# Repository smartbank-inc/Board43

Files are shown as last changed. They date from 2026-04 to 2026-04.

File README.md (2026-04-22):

# Board43

Board43 is an RP2350A-based microcontroller development board. Flash PicoRuby or your favorite firmware and start hacking.

## Directory Structure

| Directory | Description | License |
| --- | --- | --- |
| [`docs/`](./docs) | Reference manual and its compiler | MIT (compiler) / CC BY-SA 4.0 (document content) |
| [`firmware/`](./firmware) | PicoRuby-based firmware | MIT |
| [`pcb/`](./pcb) | KiCad PCB design data | CERN-OHL-W-2.0 (some files under CC BY-SA 4.0) |
| [`playground/`](./playground) | Browser-based PicoRuby IDE | MIT |
| [`workshop/`](./workshop) | Workshop materials ([Japanese](https://github.com/smartbank-inc/Board43/blob/main/workshop/README.md) / [English](https://github.com/smartbank-inc/Board43/blob/main/workshop/README_en.md)) | CC BY-SA 4.0 |

## License

Each directory in this repository is licensed independently. See the `LICENSE` file or `README` in each directory for details.

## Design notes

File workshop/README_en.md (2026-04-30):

[日本語](README.md)

# Board43 Workshop: Display Your Icon on the LED Matrix

Use Board43 and PicoRuby to display pixel art on a 16×16 LED matrix.

## What You Need

- **Board43** — Yours to keep after the workshop
- **USB Cable Type-C** — Please return after the workshop
- **Your PC** — Use Chrome or Edge

---

## 1. Set Up the Tool

### 1-1. Connect Board43 to Your PC

Connect Board43 to your PC with the USB cable.

### 1-2. Open Board43 Playground

Open the following URL in your browser.

```
https://board43-playground.smartbank.workers.dev/
```

### 1-3. Connect via Serial

The setup screen will appear.

1. Leave the Baud Rate at **115200** and press the **Connect** button

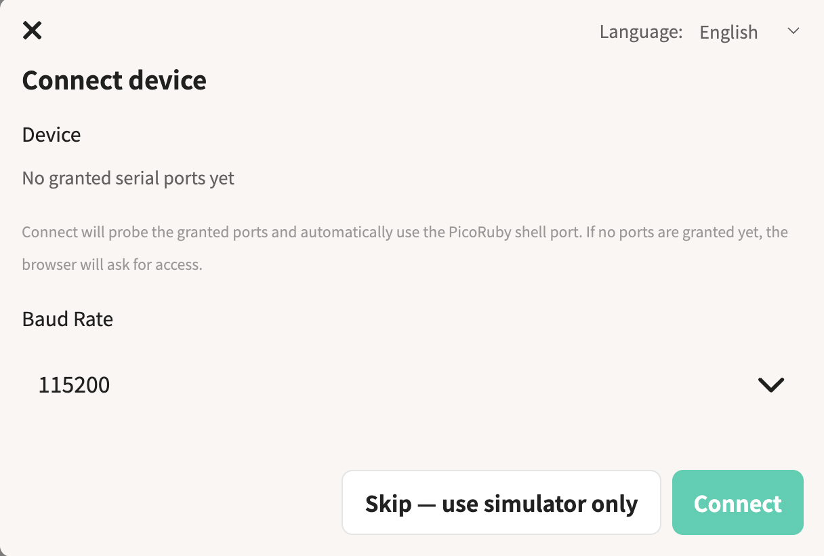
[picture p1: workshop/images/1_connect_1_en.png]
   

2. Select the serial port in the browser dialog (choose the one labeled "PicoRuby R2P2")

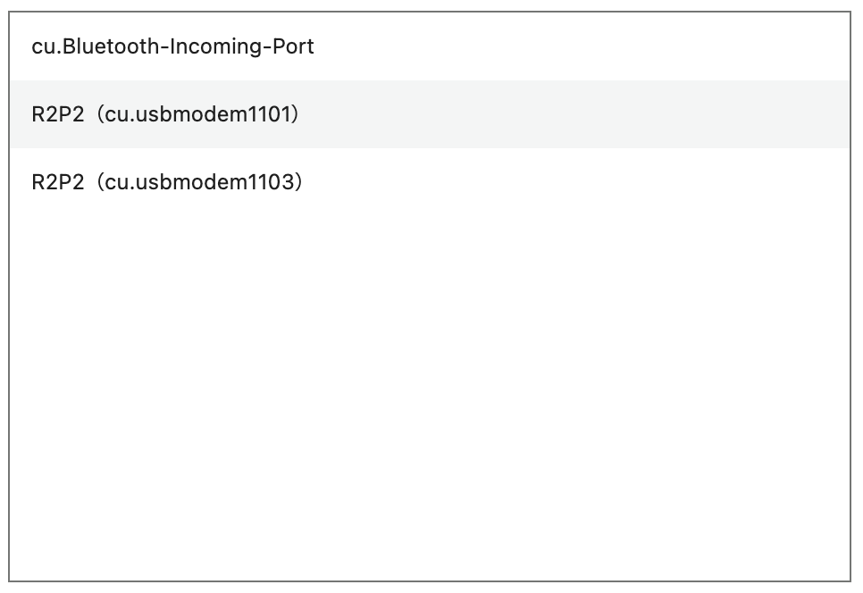
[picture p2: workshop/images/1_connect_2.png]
   

The screen will switch to show a code editor on the left, an LED simulator on the upper right, and a console at the bottom.

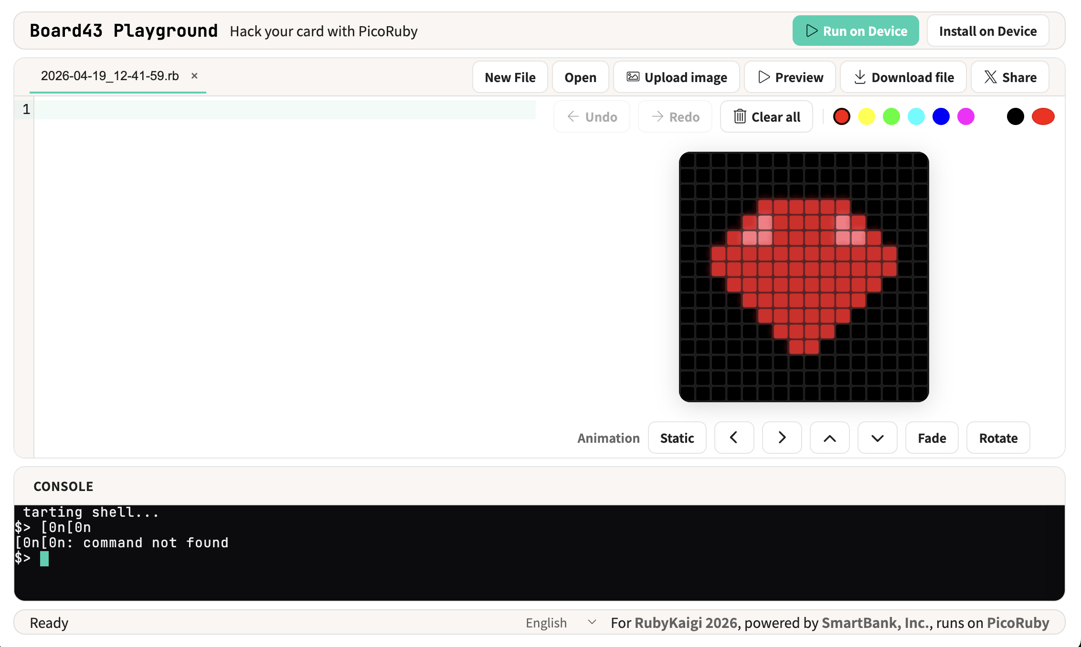
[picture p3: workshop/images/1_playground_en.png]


---

## 2. Light Up the LEDs

### 2-1. Light All LEDs in Red

Enter the following code in the editor.

```ruby
require 'ws2812-plus'

led = WS2812.new(pin: Board43::GPIO_LEDOUT, num: 256)  # GPIO 24, 256 LEDs (16×16)
led.fill(255, 0, 0)   # Set all LEDs to red (R=255, G=0, B=0)
led.show              # Send the buffer to the LEDs
```

Press the **Run on Device** button at the top of the screen.



If the entire LED matrix lights up red, it's working.

Press **Stop on Device** before running the next code.



### 2-2. Change the Color of Specific LEDs

Use `set_rgb(index, r, g, b)` to control individual LEDs.

```ruby
require 'ws2812-plus'

led = WS2812.new(pin: Board43::GPIO_LEDOUT, num: 256)

led.set_rgb(0, 0, 255, 0)      # Top-left to green
led.set_rgb(15, 0, 0, 255)     # Top-right to blue
led.set_rgb(100, 255, 255, 0)  # Index 100 to yellow

led.show
```

LED indices start at `0` in the top-left corner, going left to right, top to bottom.

```
  0   1   2   3  ...  15
 16  17  18  19  ...  31
 32  33  34  35  ...  47
  :                    :
240 241 242 243  ... 255
```

---

## 3. Animate the LEDs

Use `clear` to turn off all LEDs, and `sleep_ms` to wait in milliseconds. Repeating "off → on → wait" in a `loop` creates animation.

```ruby
require 'ws2812-plus'

led = WS2812.new(pin: Board43::GPIO_LEDOUT, num: 256)

loop do
  256.times do |i|
    led.clear                   # Turn off all LEDs
    led.set_rgb(i, 255, 0, 0)   # Light up LED i in red
    led.show
    sleep_ms 30                 # Wait 30 milliseconds
  end
end
```

Press **Run on Device** to see a red light flowing from the top-left to the bottom-right.

The `sleep_ms` value sets the frame interval — smaller values make it faster, larger values make it slower.

Press **Stop on Device** at the top of the screen to stop the program.

---

## 4. Display Your Icon

This is the main part. Use the **LED Simulator** in the upper right to create pixel art and display it on Board43.

### 4-1. Upload an Image

1. Press the **Upload image** button in the editor toolbar

   

2. Select an image file
3. It will be automatically converted to 16×16 and displayed in the simulator

### 4-2. Add Animation

Choose a display mode from the simulator toolbar.



| Option | Motion |
| --- | --- |
| Static | Static display  |
| ← | Scroll left |
| → | Scroll right |
| ↑ | Scroll up |
| ↓ | Scroll down |
| Fade | Fade in and out |
| Rotate | Rotate |

### 4-3. Preview in the Simulator

Press the **Preview** button in the editor to auto-generate code and preview the animation in the simulator.



### 4-4. Transfer to Board43

Press the **Run on Device** button at the top of the screen to display it on the Board43 LED matrix.

### 4-5. Tilt the Board

Try flipping Board43 upside down. The icon orientation changes automatically. The code generated from the uploaded image includes accelerometer-based orientation detection.

### 4-6. Experiment Freely

Change the pixel art or animation and try as many times as you like. Keep experimenting until you're satisfied.

### 4-7. Auto-Run on Power Up

Press the **Install on Device** button at the top of the screen to save the current code as `/home/app.rb`. From next time, the LEDs will light up just by powering on. It works with a mobile battery without a PC connection. On boot, the status LED blinks 10 times before app.rb starts.

To disable auto-run, skip the auto-run first, then delete or rename app.rb.

1. Hold the **SW3** button on the board and press the **RUN** button to reboot
2. Keep holding **SW3** until the status LED flashes 3 times
3. Press **Connect** again in the Playground screen, then delete or rename app.rb from the console

```
mv /home/app.rb /home/old.rb
```

### 4-8. Share Your Code

Press the **Share** button in the editor toolbar to generate a shareable URL. You can copy the link or post it to X (Twitter). Opening the shared link will load the code in Board43 Playground.

---

## 5. What Board43 Can Do

Board43 has a 6-axis IMU (accelerometer + gyroscope), buzzer, and switches in addition to the LED matrix.

**Demo: Theremin (theremin.rb)**
Tilt the board to play a musical scale. The LED shows the current note position. Uses the IMU, buzzer, LED, and switches.

The sample code is available on GitHub. Try it on your own Board43.

https://github.com/smartbank-inc/Board43/tree/main/workshop/examples

### Other Features

**Editor Toolbar**

| Button | Description |
| --- | --- |
| New File | Create a new file |
| Open | Open a file saved on Board43 |
| Download | Save the current file to your PC |

**Console**

The console is a PicoRuby shell. You can run commands directly from the terminal.

```
/home/my_program.rb   # Run a file
```

Press **Ctrl + C** to stop a running program.

```
ls /home          # List files
cat /home/app.rb  # Display file contents
mv /home/app.rb /home/old.rb  # Rename a file
```

---

## 6. Cleanup

Disconnect the USB cable and leave it on the desk. Please take Board43 home with you.

Please fill out the [survey](https://docs.google.com/forms/d/e/1FAIpQLSeV5AyQW6vzZo-vfc9GZmv4xTpa_p-nzMFEPl0KW-F13QeOgA/viewform). Your feedback will help us improve future workshops.

We'll be at this hack space after the workshop. We'd love to see what you've made. Feel free to ask questions too.

Sharing on social media is very welcome. We'd love it if you use the hashtag **#board43**.

---

## Troubleshooting

**LEDs don't light up**
→ Check that the USB cable is securely connected. If `>` appears in the console, the connection is working.

**The program won't stop**
→ Press the **Stop on Device** button at the top of the screen.

**Serial port not found**
→ Make sure you're using Chrome or Edge. Firefox and Safari don't support the Web Serial API.

**The screen is frozen**
→ Reload the browser and Connect again.

---

## License

[CC BY-SA 4.0](https://creativecommons.org/licenses/by-sa/4.0/), Attribution-ShareAlike 4.0 International.

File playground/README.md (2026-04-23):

# Board43 Playground

A browser-based PicoRuby IDE for the Board43.

## Features

### Editor

- Multi-file tabs with CodeMirror 6 (Ruby syntax highlighting)
- Create, open from device, and download files
- Context menu (cut/copy/paste)
- Inline LED simulator panel
  - Run Ruby code in-browser via PicoRuby WASM
  - 16x16 LED matrix preview
  - Pixel paint editor with color picker, undo/redo
  - Image upload (converts to LED pixel data, via [board43-image-transformer](./lib/board43-image-transformer) WASM)
  - Animation modes: Static, Scroll (Left/Right/Up/Down), Fade, Rotate

### Device Connection

- Web Serial API for Board43 hardware
- Setup wizard with serial port selection and baud rate configuration
- Run code on device / stop (Ctrl-C)
- Install as startup program (`/home/app.rb`)

### Terminal

- Ghostty-based serial console

### General

- Language support: English / Japanese
- Simulator-only mode (no device required)

## Getting started

Requires Node.js and `pnpm`.

```bash
pnpm install
pnpm dev
```

Open the printed URL in Chrome or Edge. Web Serial API is required for the
device features; the simulator works in any modern browser.

### Build

```bash
pnpm build
```

Emits a static SPA to `dist/`. Serve it with any static host.

## License

MIT. See [LICENSE](./LICENSE) for detail.

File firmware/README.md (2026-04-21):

# Firmware

## Submodules

- [PicoRuby](https://github.com/picoruby/picoruby) [`3.4.2`](https://github.com/picoruby/picoruby/tree/9b94521d56e6082793db861801546fc5808b5211)

R2P2 lives inside PicoRuby as the `picoruby-r2p2` mrbgem, and Pico SDK / Pico Extras are pulled in under it as nested submodules.

## Setup, Build, and Flash

See [docs](../docs) for detail.

## Release (CI build)

Pushing a tag shaped `firmware-YYYY-MM-DD-NN` triggers [`build-firmware.yml`](../.github/workflows/build-firmware.yml), which builds the UF2, uploads it as a workflow artifact, and creates a GitHub Release for the tag with the UF2 attached.

```console
$ git tag firmware-2026-04-15-01
$ git push origin firmware-2026-04-15-01
```

`NN` is a two-digit sequence for multiple builds on the same day (`01`, `02`, ...). The workflow also accepts manual runs via `workflow_dispatch` in the GitHub Actions UI.

Download the built UF2 from the [Releases](https://github.com/smartbank-inc/Board43-draft/releases) page, or via CLI:

```console
$ gh release download firmware-2026-04-15-01 --pattern '*.uf2'
```

## License

MIT. See [LICENSE](./LICENSE) for detail.

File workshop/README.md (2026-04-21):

[English](README_en.md)

# Board43 ワークショップ: 自分のアイコンをLEDマトリクスに表示しよう

Board43とPicoRubyを使って、16×16のLEDマトリクスにドット絵で表示させます。

## 使うもの

- **Board43** — ワークショップ後はお持ち帰りいただけます
- **USBケーブル Type-C** — ワークショップ後にお戻しください
- **ご自身のPC** — Chrome または Edge を使います

---

## 1. ツールを立ち上げる

### 1-1. Board43をPCに接続する

USBケーブルでBoard43をPCにつなぎます。

### 1-2. Board43 Playgroundを開く

ブラウザで以下のURLにアクセスします。

```
https://board43-playground.smartbank.workers.dev/
```

### 1-3. シリアル接続する

セットアップ画面が表示されます。

1. Baud Rate は **115200** のまま、 **Connect** ボタンを押す

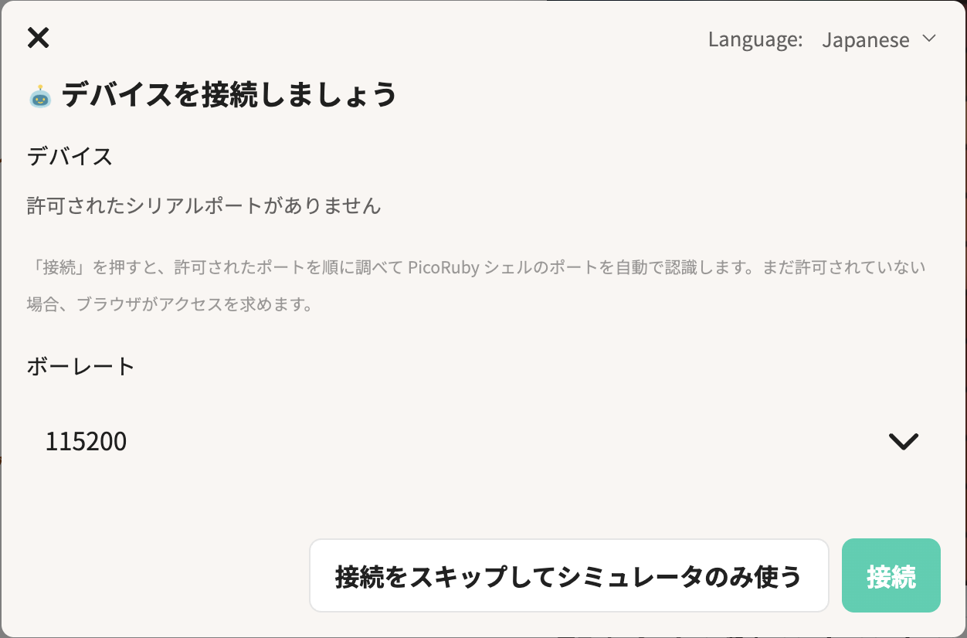
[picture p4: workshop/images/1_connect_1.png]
    

2. ブラウザのダイアログでシリアルポートを選ぶ（「PicoRuby R2P2」と表示されるものを選んでください）

    
    
画面が切り替わり、左にコードエディタ、右上にLEDシミュレータ、下にコンソールが表示されます。

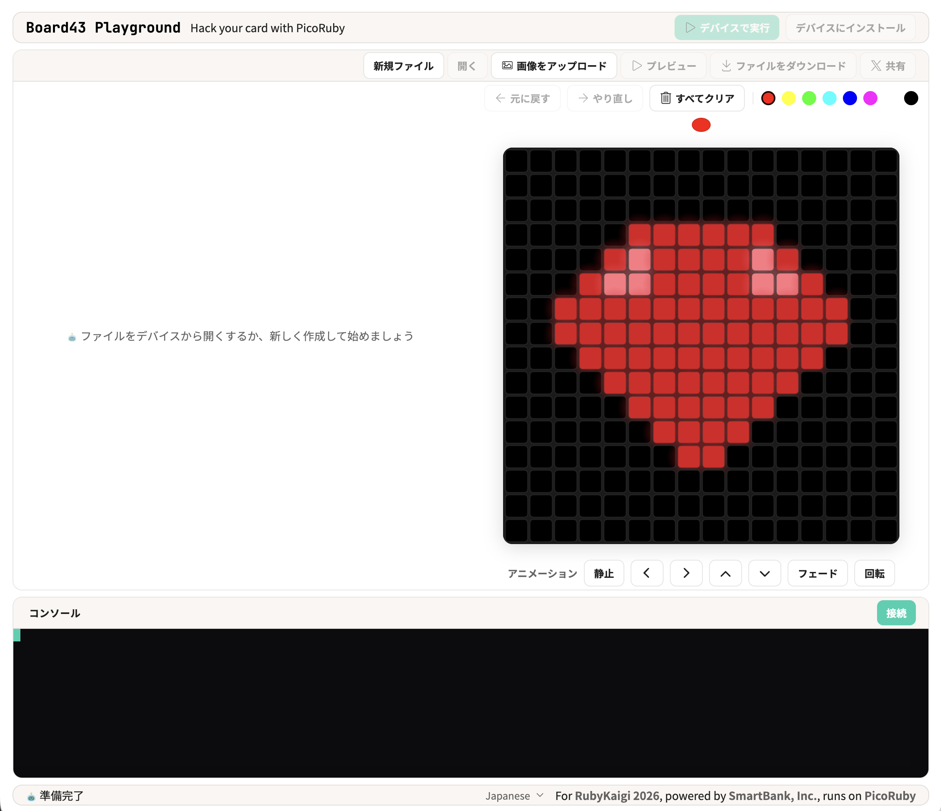
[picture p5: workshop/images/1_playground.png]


---

## 2. LEDを光らせてみよう

### 2-1. 全部赤く光らせる

エディタに以下のコードを入力します。

```ruby
require 'ws2812-plus'

led = WS2812.new(pin: Board43::GPIO_LEDOUT, num: 256)  # GPIO 24, LED 256個（16×16）
led.fill(255, 0, 0)   # 全LEDを赤（R=255, G=0, B=0）に
led.show              # バッファの内容をLEDに送信
```

画面上部の **Run on Device** ボタンを押してください。



LEDマトリクスが全面赤く光れば成功です。

次のコードを実行する前に **Stop on Device** を押してください。



### 2-2. 好きな場所の色を変える

`set_rgb(index, r, g, b)` で個別のLEDを指定できます。

```ruby
require 'ws2812-plus'

led = WS2812.new(pin: Board43::GPIO_LEDOUT, num: 256)

led.set_rgb(0, 0, 255, 0)      # 左上を緑に
led.set_rgb(15, 0, 0, 255)     # 右上を青に
led.set_rgb(100, 255, 255, 0)  # 100番目を黄色に

led.show
```

LEDのインデックスは左上が `0` で、左から右・上から下の順に並んでいます。

```
  0   1   2   3  ...  15
 16  17  18  19  ...  31
 32  33  34  35  ...  47
  :                    :
240 241 242 243  ... 255
```

---

## 3. アニメーションさせよう

`clear` で全消灯、`sleep_ms` でミリ秒単位の待機ができます。`loop` で「消灯→点灯→待機」を繰り返すことでアニメーションになります。

```ruby
require 'ws2812-plus'

led = WS2812.new(pin: Board43::GPIO_LEDOUT, num: 256)

loop do
  256.times do |i|
    led.clear                   # 全LED消灯
    led.set_rgb(i, 255, 0, 0)   # i番目を赤く光らせる
    led.show
    sleep_ms 30                 # 30ミリ秒待つ
  end
end
```

**Run on Device** で実行すると、赤い光が左上から右下へ流れていきます。

`sleep_ms` の値がフレーム間隔になるので、値を小さくすると速く、大きくするとゆっくり流れます。

プログラムを止めるときは画面上部の **Stop on Device** ボタンを押してください。

---

## 4. 自分のアイコンを光らせよう

ここからがメインです。画面右上の **LEDシミュレータ** を使ってドット絵を作り、Board43に表示させます。

### 4-1. 画像をアップロードする

1. エディタのツールバーにある **Upload image** ボタンを押す

    

2. 画像ファイルを選択する
3. 自動的に16×16に変換されてシミュレータに表示される

### 4-2. アニメーションをつける

シミュレータのツールバーで、表示方法を選べます。



| 選択肢 | 動き |
| --- | --- |
| Static | 静止表示 |
| ← | 左にスクロール |
| → | 右にスクロール |
| ↑ | 上にスクロール |
| ↓ | 下にスクロール |
| Fade | フェードイン・アウト |

### 4-3. シミュレータで確認する

エディタの **Preview** ボタンを押すと、コードが自動生成され、アニメーションがシミュレータ上でプレビューできます。



### 4-4. Board43に転送して光らせる

画面上部の **Run on Device** ボタンを押すと、Board43のLEDマトリクスに表示されます。

### 4-5. ボードを傾けてみよう

Board43を上下にひっくり返してみてください。アイコンの向きが自動的に変わります。アップロードした画像から生成されるコードには、加速度センサーで上下を検知する処理が含まれています。

### 4-6. 自由に試してみよう

ドット絵やアニメーションを変えて、何度でも試せます。納得いくまでいろいろ試してみてください。

### 4-7. 電源を入れただけでコードを実行する

画面上部の **Install on Device** ボタンを押すと、現在のコードが `/home/app.rb` として保存され、次回から電源を入れるだけでLEDが光ります。PCに接続しなくても、モバイルバッテリーで動きます。起動時にステータスLEDが10回点滅したあとに app.rb が実行されます。

自動起動を解除したい場合は、自動起動をスキップしてから app.rb を削除・変更します。

1. 基板の **SW3** ボタンを押したまま **RUN** ボタンを押して再起動する
2. ステータスLEDが3回フラッシュするまで **SW3** ボタンを押したままにする
3. Playground画面で **Connect** を押し直し、コンソールから app.rb を削除または別名に変更する

```
mv /home/app.rb /home/old.rb
```

### 4-8. コードをシェアしよう

エディタツールバーの **Share** ボタンを押すと、共有用のURLが生成されます。リンクをコピーしたり、X（Twitter）に投稿できます。共有リンクを開くと、Board43 Playgroundにコードが展開されます。

---

## 5. Board43でできること

Board43にはLEDマトリクス以外にも、6軸IMU（加速度・ジャイロセンサー）、ブザー、スイッチが搭載されています。

**デモ: テルミン（theremin.rb）**
ボードを傾けて音階を演奏できます。LEDが現在の音の位置を表示します。IMU、ブザー、LED、スイッチを使っています。

このサンプルコードはGitHubで公開しています。ご自身のBoard43でぜひ試してみてください。

https://github.com/smartbank-inc/Board43/workshop/examples

### その他の機能

**エディタのツールバー**

| ボタン | 説明 |
| --- | --- |
| New File | 新しいファイルを作成する |
| Open | Board43に保存されているファイルを開く |
| Download | 現在のファイルをPCに保存する |

**コンソール**

コンソールはPicoRubyのシェルです。ターミナルから直接コマンドを実行できます。

```
/home/my_program.rb   # ファイルを指定して実行
```

実行中のプログラムは **Ctrl + C** で停止できます。

```
ls /home          # ファイル一覧
cat /home/app.rb  # ファイルの中身を表示
mv /home/app.rb /home/old.rb  # ファイル名の変更
```

---

## 6. 片付け

USBケーブルを外して、机の上に置いてください。Board43はお持ち帰りください。

[アンケート](https://docs.google.com/forms/d/e/1FAIpQLSeV5AyQW6vzZo-vfc9GZmv4xTpa_p-nzMFEPl0KW-F13QeOgA/viewform)にご協力ください。今後のワークショップの参考にさせていただきます。

ワークショップ後もこのハックスペースにいます。できたものを見せに来てもらえるとうれしいです。質問もお気軽にどうぞ。

SNSでのシェアも大歓迎です。 **#board43** をつけてもらえると見に行けるのでうれしいです。

---

## トラブルシューティング

**LEDが光らない**
→ USBケーブルがしっかり接続されているか確認してください。コンソールに `>` が表示されていれば接続は正常です。

**プログラムが止まらない**
→ 画面上部の **Stop on Device** ボタンを押してください。

**シリアルポートが見つからない**
→ Chrome または Edge を使っているか確認してください。Firefox や Safari は Web Serial API に対応していません。

**画面が固まった**
→ ブラウザをリロードして、再度 Connect してください。

---

## License

[CC BY-SA 4.0](https://creativecommons.org/licenses/by-sa/4.0/), Attribution-ShareAlike 4.0 International.

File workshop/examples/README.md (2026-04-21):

[English](README_en.md)

# Board43 サンプルコード

## センサーごとのサンプル

| ファイル | 説明 | 使用機能 |
| --- | --- | --- |
| [status_led.rb](status_led.rb) | ステータスLEDのオン・オフ | GPIO |
| [button.rb](button.rb) | ボタンの押下状態を読み取る | スイッチ (GPIO) |
| [buzzer.rb](buzzer.rb) | ブザーを鳴らす・止める | ブザー (PWM) |
| [led_matrix.rb](led_matrix.rb) | LEDマトリクスに虹色グラデーションを表示する | LED (WS2812) |
| [imu.rb](imu.rb) | 加速度・ジャイロ・温度の値をコンソールに表示する | IMU (I2C) |

## 複合サンプル

| ファイル | 説明 | 使用機能 |
| --- | --- | --- |
| [water.rb](water.rb) | ボードを傾けると水が流れる流体シミュレーション | IMU + LED |
| [logo.rb](logo.rb) | RubyKaigi 2026ロゴ表示＋ボタンで背景エフェクト切り替え | スイッチ + LED + ブザー |
| [drum.rb](drum.rb) | 4つのボタンで叩くドラム | スイッチ (IRQ) + LED + ブザー |
| [snake_game.rb](snake_game.rb) | ボタンで操作するスネークゲーム | スイッチ + LED + ブザー |
| [theremin.rb](theremin.rb) | ボードを傾けて音階を演奏するテルミン | IMU + LED + ブザー + スイッチ |

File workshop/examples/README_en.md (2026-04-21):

[日本語](README.md)

# Board43 Sample Code

## Per-Sensor Samples

| File | Description | Features Used |
| --- | --- | --- |
| [status_led.rb](status_led.rb) | Toggle the status LED on/off | GPIO |
| [button.rb](button.rb) | Read button press state | Switches (GPIO) |
| [buzzer.rb](buzzer.rb) | Play and stop the buzzer | Buzzer (PWM) |
| [led_matrix.rb](led_matrix.rb) | Display a rainbow gradient on the LED matrix | LED (WS2812) |
| [imu.rb](imu.rb) | Print acceleration, gyroscope, and temperature to console | IMU (I2C) |

## Combined Samples

| File | Description | Features Used |
| --- | --- | --- |
| [water.rb](water.rb) | Tilt the board to make water flow — a fluid simulation | IMU + LED |
| [logo.rb](logo.rb) | RubyKaigi 2026 logo display with button-switchable background effects | Switches + LED + Buzzer |
| [drum.rb](drum.rb) | Play drums with 4 buttons | Switches (IRQ) + LED + Buzzer |
| [snake_game.rb](snake_game.rb) | Classic snake game controlled with buttons | Switches + LED + Buzzer |
| [theremin.rb](theremin.rb) | Tilt the board to play a musical scale | IMU + LED + Buzzer + Switches |

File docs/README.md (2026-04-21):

# docs

Reference manual and its compiler.

## Prerequisites

- [Rust](https://www.rust-lang.org/)

## Usage

```console
$ cargo run -- compile
```

## Release (CI build)

Pushing a tag shaped `document-MAJOR.MINOR.PATCH` triggers [`build-document.yml`](../.github/workflows/build-document.yml), which compiles the reference manual and creates a GitHub Release for the tag with the PDF attached.

```console
$ git tag document-1.0.0
$ git push origin document-1.0.0
```

The workflow also accepts manual runs via `workflow_dispatch` in the GitHub Actions UI (manual runs build the PDF but do not create a release).

If a document release is published after a firmware release, keep the firmware release marked as "Latest release" on GitHub (uncheck "Set as the latest release" when creating the document release). The reference manual directs readers to [`releases/latest`](https://github.com/smartbank-inc/Board43/releases/latest) for firmware downloads, so that tag must continue to resolve to the shippable firmware build.

Download the released PDF from the [Releases](https://github.com/smartbank-inc/Board43-draft/releases) page, or via CLI:

```console
$ gh release download document-1.0.0 --pattern '*.pdf'
```

## License

Source code (the document compiler) is licensed under the MIT. See [LICENSE](./LICENSE) for detail.

Document content (the reference manual text and assets) is licensed under [Creative Commons Attribution-ShareAlike 4.0 International (CC BY-SA 4.0)](https://creativecommons.org/licenses/by-sa/4.0/). Product names, trademarks, and registered trademarks referenced in this manual are the property of their respective owners. The license above does not grant any rights to use them.

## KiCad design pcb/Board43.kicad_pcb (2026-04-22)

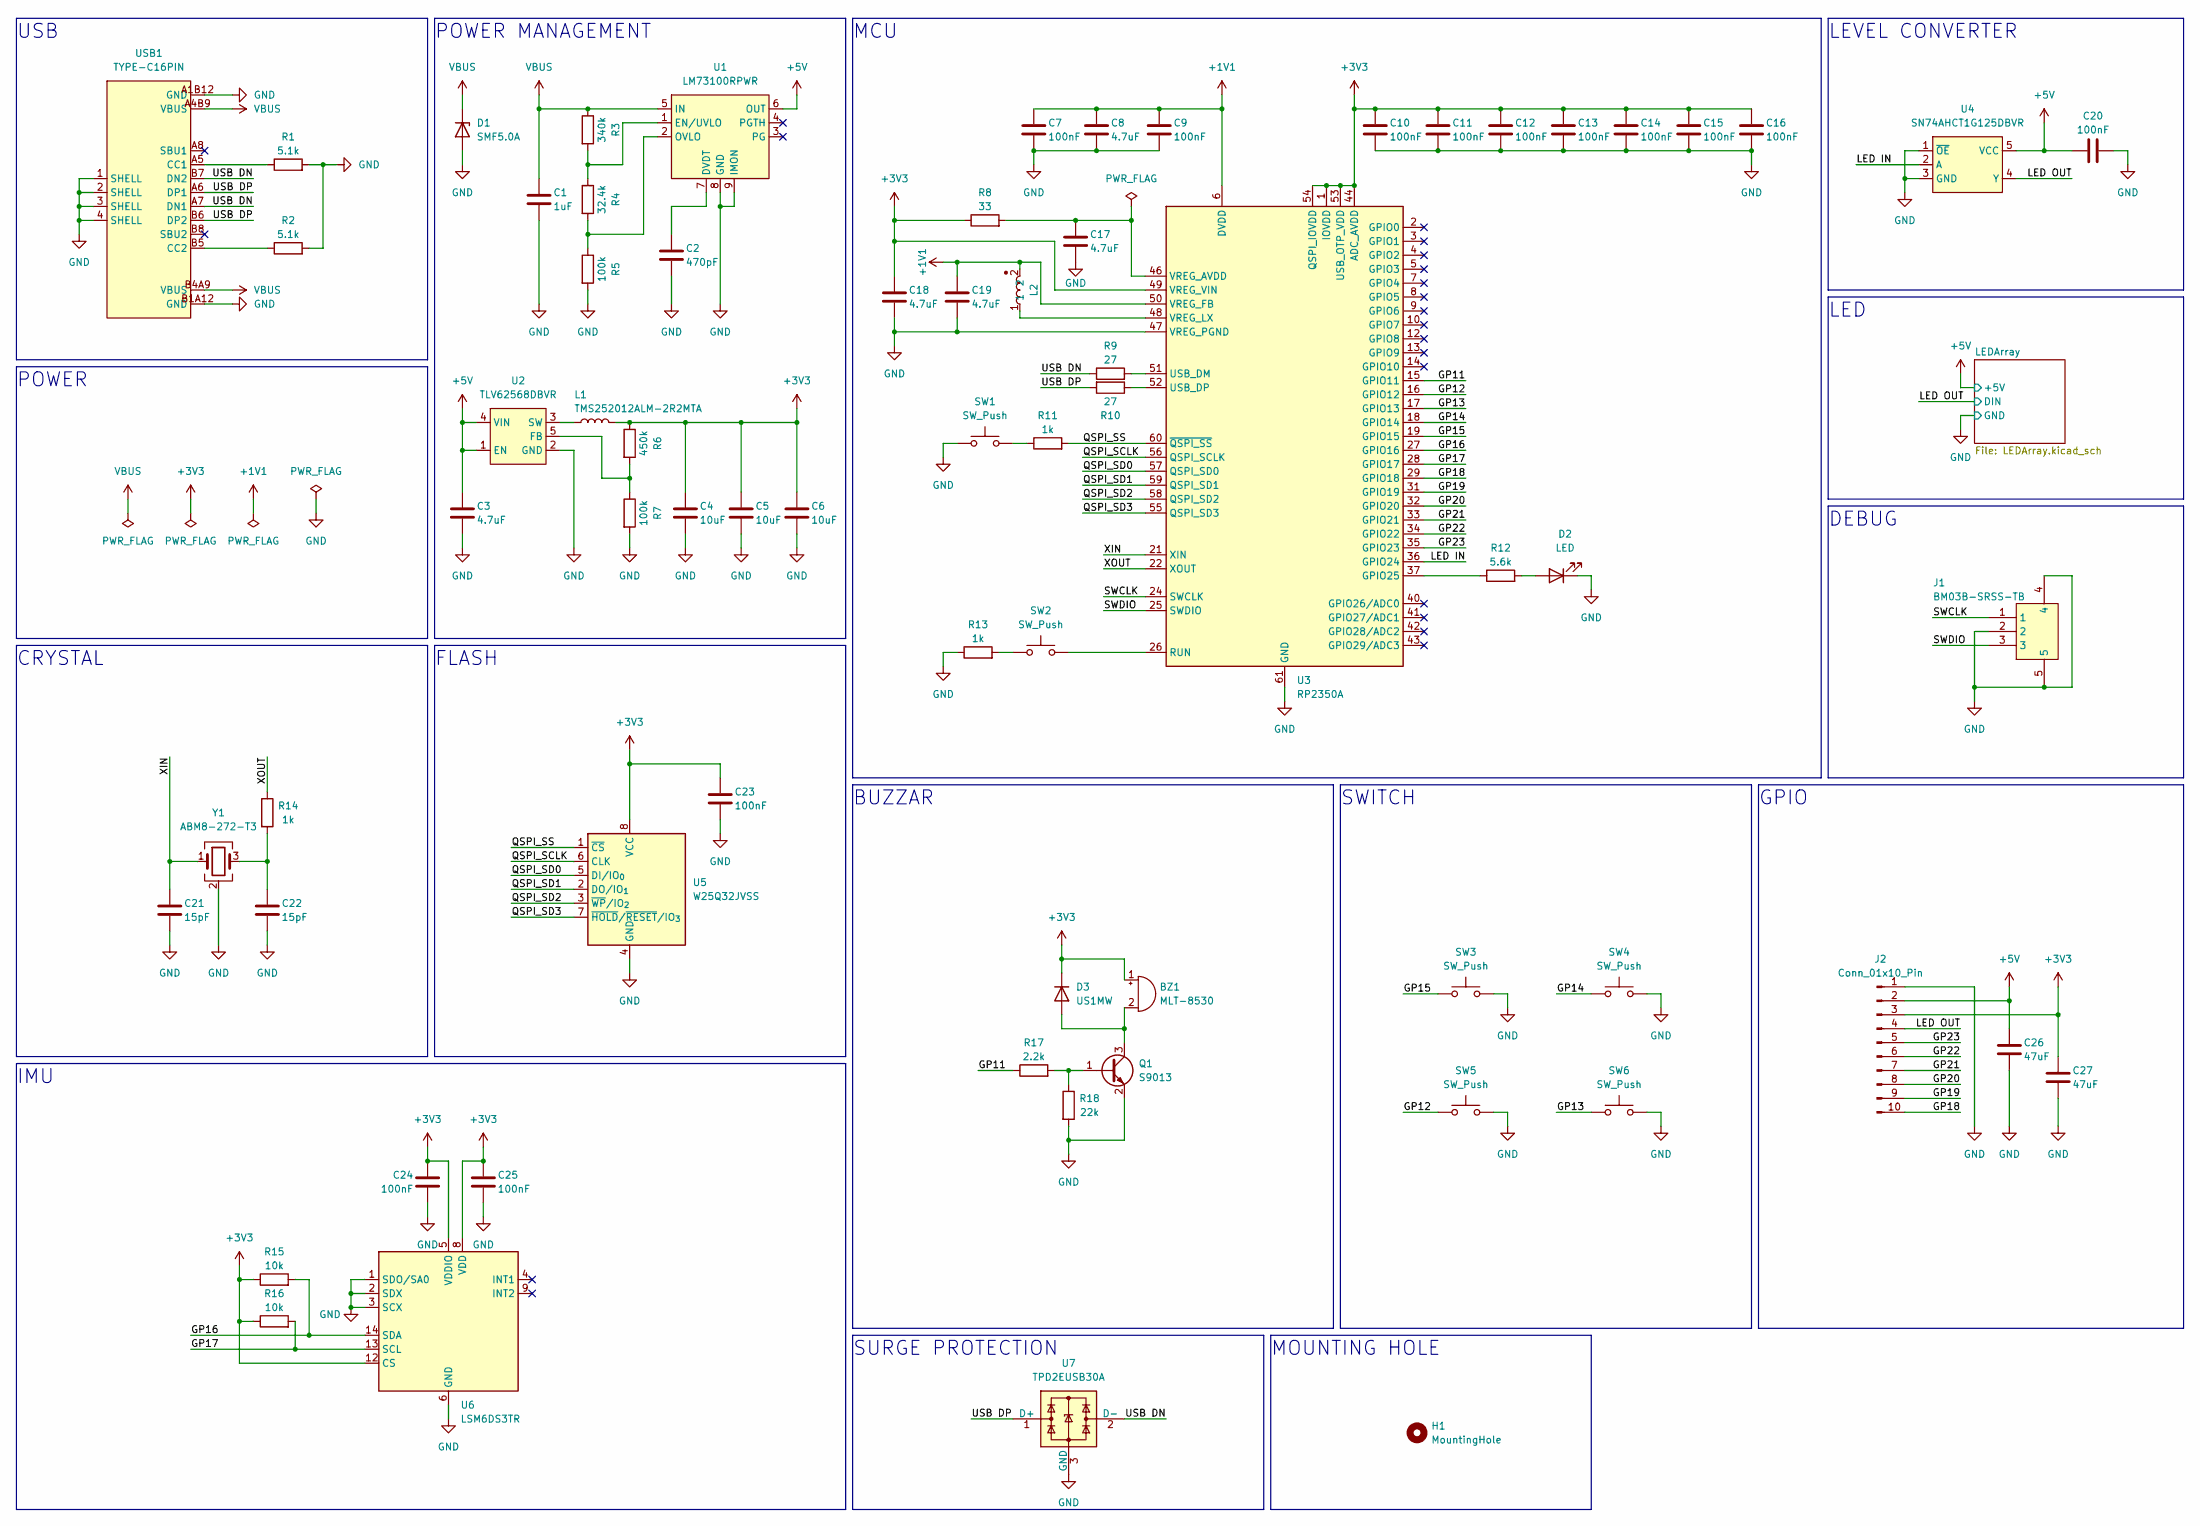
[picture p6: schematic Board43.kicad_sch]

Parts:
BZ1: MLT-8530; LCSC C94599
C1: 1uF; C_0402_1005Metric; LCSC C528974
C2: 470pF; C_0201_0603Metric; LCSC C384950
C3, C8, C17: 4.7uF; C_0402_1005Metric; LCSC C368809
C4, C5, C6: 10uF; C_0603_1608Metric; LCSC C2959727
C7, C9, C10, C11, C12, C13, C14, C15, C16: 100nF; C_0201_0603Metric; LCSC C668346
C18, C19: 4.7uF; C_0402_1005Metric_Narrow; LCSC C368809
C20, C23, C24, C25: 100nF; C_0402_1005Metric; LCSC C1525
C21, C22: 15pF; C_0402_1005Metric; LCSC C76950
C26, C27: 47uF; C_1206_3216Metric; LCSC C96123
D1: SMF5.0A; D_SOD-123F; LCSC C193402
D2: LED; KT-0603W; LCSC C2290
D3: US1MW; D_SOD-123F; LCSC C116132
H1: MountingHole; MountingHole_3.2mm_M3
J1: BM03B-SRSS-TB; LCSC C160389
J2: Conn_01x10_Pin; PinHeader_1x10_P2.54mm_Vertical
L1: TMS252012ALM-2R2MTA; L_1008_2520Metric; LCSC C1017131
L2: L; AOTA-B201610S3R3-101-T; LCSC C42411119
Q1: S9013; SOT-23; LCSC C727139
R1, R2: 5.1k; R_0201_0603Metric; LCSC C270344
R3: 340k; R_0402_1005Metric; LCSC C423187
R4: 32.4k; R_0402_1005Metric; LCSC C26974
R5, R7: 100k; R_0402_1005Metric; LCSC C25741
R6: 450k; R_0402_1005Metric; LCSC C5159688
R8: 33; R_0402_1005Metric; LCSC C25105
R9, R10: 27; R_0201_0603Metric; LCSC C473051
R11, R13, R14: 1k; R_0201_0603Metric; LCSC C270365
R12: 5.6k; R_0201_0603Metric; LCSC C423481
R15, R16: 10k; R_0201_0603Metric; LCSC C270334
R17: 2.2k; R_0402_1005Metric; LCSC C25879
R18: 22k; R_0402_1005Metric; LCSC C25768
SW1, SW2, SW3, SW4, SW5, SW6: SW_Push; SKRPACE010; LCSC C139797
U1: LM73100RPWR; LCSC C3210761
U2: TLV62568DBVR; SOT-23-5; LCSC C163219
U3: RP2350A; LCSC C42411118
U4: SN74AHCT1G125DBVR; SOT-23-5; LCSC C7484
U5: W25Q32JVSS; SOIC-8_5.3x5.3mm_P1.27mm; LCSC C82344
U6: LSM6DS3TR; LGA-14_3x2.5mm_P0.5mm_LayoutBorder3x4y; LCSC C95230
U7: TPD2EUSB30A; TPD2EUSB30ADRTR; LCSC C94934
USB1: TYPE-C16PIN; LCSC C393939
Y1: ABM8-272-T3; Crystal_SMD_3225-4Pin_3.2x2.5mm; LCSC C20625731

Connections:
+1V1: C7.1, C8.1, C9.1, C19.1, L2.2, U3.6 (DVDD), U3.23 (DVDD), U3.39 (DVDD), U3.50 (VREG_FB)
+3V3: BZ1.1 (+), C4.1, C5.1, C6.1, C10.1, C11.1, C12.1, C13.1, C14.1, C15.1, C16.1, C18.1, C23.1, C24.2, C25.1, C27.1, D3.1 (K), J2.3, L1.2, R6.1, R8.1, R15.1, R16.1, U3.1 (IOVDD), U3.11 (IOVDD), U3.20 (IOVDD), U3.30 (IOVDD), U3.38 (IOVDD), U3.44 (ADC_AVDD), U3.45 (IOVDD), U3.49 (VREG_VIN), U3.53 (USB_OTP_VDD), U3.54 (QSPI_IOVDD), U5.8 (VCC), U6.5 (VDDIO), U6.8 (VDD), U6.12 (CS)
+5V: C3.1, C20.1, C26.1, J2.2, U1.6 (OUT), U2.1 (EN), U2.4 (VIN), U4.5 (VCC); also elsewhere on the board
/GP11: R17.1, U3.15 (GPIO11)
/GP12: SW5.1, U3.16 (GPIO12)
/GP13: SW6.1, U3.17 (GPIO13)
/GP14: SW4.1, U3.18 (GPIO14)
/GP15: SW3.1, U3.19 (GPIO15)
/GP16: R15.2, U3.27 (GPIO16), U6.14 (SDA)
/GP17: R16.2, U3.28 (GPIO17), U6.13 (SCL)
/GP18: J2.10, U3.29 (GPIO18)
/GP19: J2.9, U3.31 (GPIO19)
/GP20: J2.8, U3.32 (GPIO20)
/GP21: J2.7, U3.33 (GPIO21)
/GP22: J2.6, U3.34 (GPIO22)
/GP23: J2.5, U3.35 (GPIO23)
/LED IN: U3.36 (GPIO24), U4.2 (A)
/LED OUT: J2.4, U4.4 (Y); also elsewhere on the board
/QSPI_SCLK: U3.56 (QSPI_SCLK), U5.6 (CLK)
/QSPI_SD0: U3.57 (QSPI_SD0), U5.5 (DI/IO_{0})
/QSPI_SD1: U3.59 (QSPI_SD1), U5.2 (DO/IO_{1})
/QSPI_SD2: U3.58 (QSPI_SD2), U5.3 (~WP/IO_{2})
/QSPI_SD3: U3.55 (QSPI_SD3), U5.7 (~HOLD/~RESET/IO_{3})
/QSPI_SS: R11.2, U3.60 (~QSPI_SS), U5.1 (~CS)
/SWCLK: J1.1, U3.24 (SWCLK)
/SWDIO: J1.3, U3.25 (SWDIO)
/USB DN: R9.1, U7.2 (D-), USB1.A7 (DN1), USB1.B7 (DN2)
/USB DP: R10.2, U7.1 (D+), USB1.A6 (DP1), USB1.B6 (DP2)
/XIN: C21.1, U3.21 (XIN), Y1.1
/XOUT: R14.1, U3.22 (XOUT)
GND: C1.2, C2.2, C3.2, C4.2, C5.2, C6.2, C7.2, C8.2, C9.2, C10.2, C11.2, C12.2, C13.2, C14.2, C15.2, C16.2, C17.2, C18.2, C19.2, C20.2, C21.2, C22.2, C23.2, C24.1, C25.2, C26.2, C27.2, D1.2 (A), D2.1 (K), J1.2, J1.4, J1.5, J2.1, Q1.2 (E), R1.2, R2.2, R5.2, R7.2, R13.1, R18.2, SW1.1, SW3.2, SW4.2, SW5.2, SW6.2, U1.8 (GND), U1.9 (IMON), U2.2 (GND), U3.47 (VREG_PGND), U3.61 (GND), U4.1 (~OE), U4.3 (GND), U5.4 (GND), U6.1 (SDO/SA0), U6.2 (SDX), U6.3 (SCX), U6.6 (GND), U6.7 (GND), U7.3 (GND), USB1.1 (SHELL), USB1.2 (SHELL), USB1.3 (SHELL), USB1.4 (SHELL), USB1.A1B12 (GND), USB1.B1A12 (GND), Y1.2 (G), Y1.4 (G); also elsewhere on the board
unnamed: BZ1.2 (-), D3.2 (A), Q1.3 (C)
unnamed: C22.1, R14.2, Y1.3
unnamed: D2.2 (A), R12.2
unnamed: Q1.1 (B), R17.2, R18.1
unnamed: R11.1, SW1.2
unnamed: R13.2, SW2.1
unnamed: C2.1, U1.7 (DVDT)
unnamed: R3.2, R4.1, U1.1 (EN/UVLO)
unnamed: R4.2, R5.1, U1.2 (OVLO)
unnamed: R6.2, R7.1, U2.5 (FB)
unnamed: L1.1, U2.3 (SW)
unnamed: R12.1, U3.37 (GPIO25)
unnamed: SW2.2, U3.26 (RUN)
unnamed: R9.2, U3.51 (USB_DM)
unnamed: R10.1, U3.52 (USB_DP)
unnamed: C17.1, R8.2, U3.46 (VREG_AVDD)
unnamed: L2.1, U3.48 (VREG_LX)
unnamed: R1.1, USB1.A5 (CC1)
unnamed: R2.1, USB1.B5 (CC2)
VBUS: C1.1, D1.1 (K), R3.1, U1.5 (IN), USB1.A4B9 (VBUS), USB1.B4A9 (VBUS)

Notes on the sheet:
GPIO
MOUNTING HOLE
SWITCH
USB
SURGE PROTECTION
FLASH
LED
DEBUG
MCU
IMU
LEVEL CONVERTER
CRYSTAL
POWER
BUZZAR
POWER MANAGEMENT

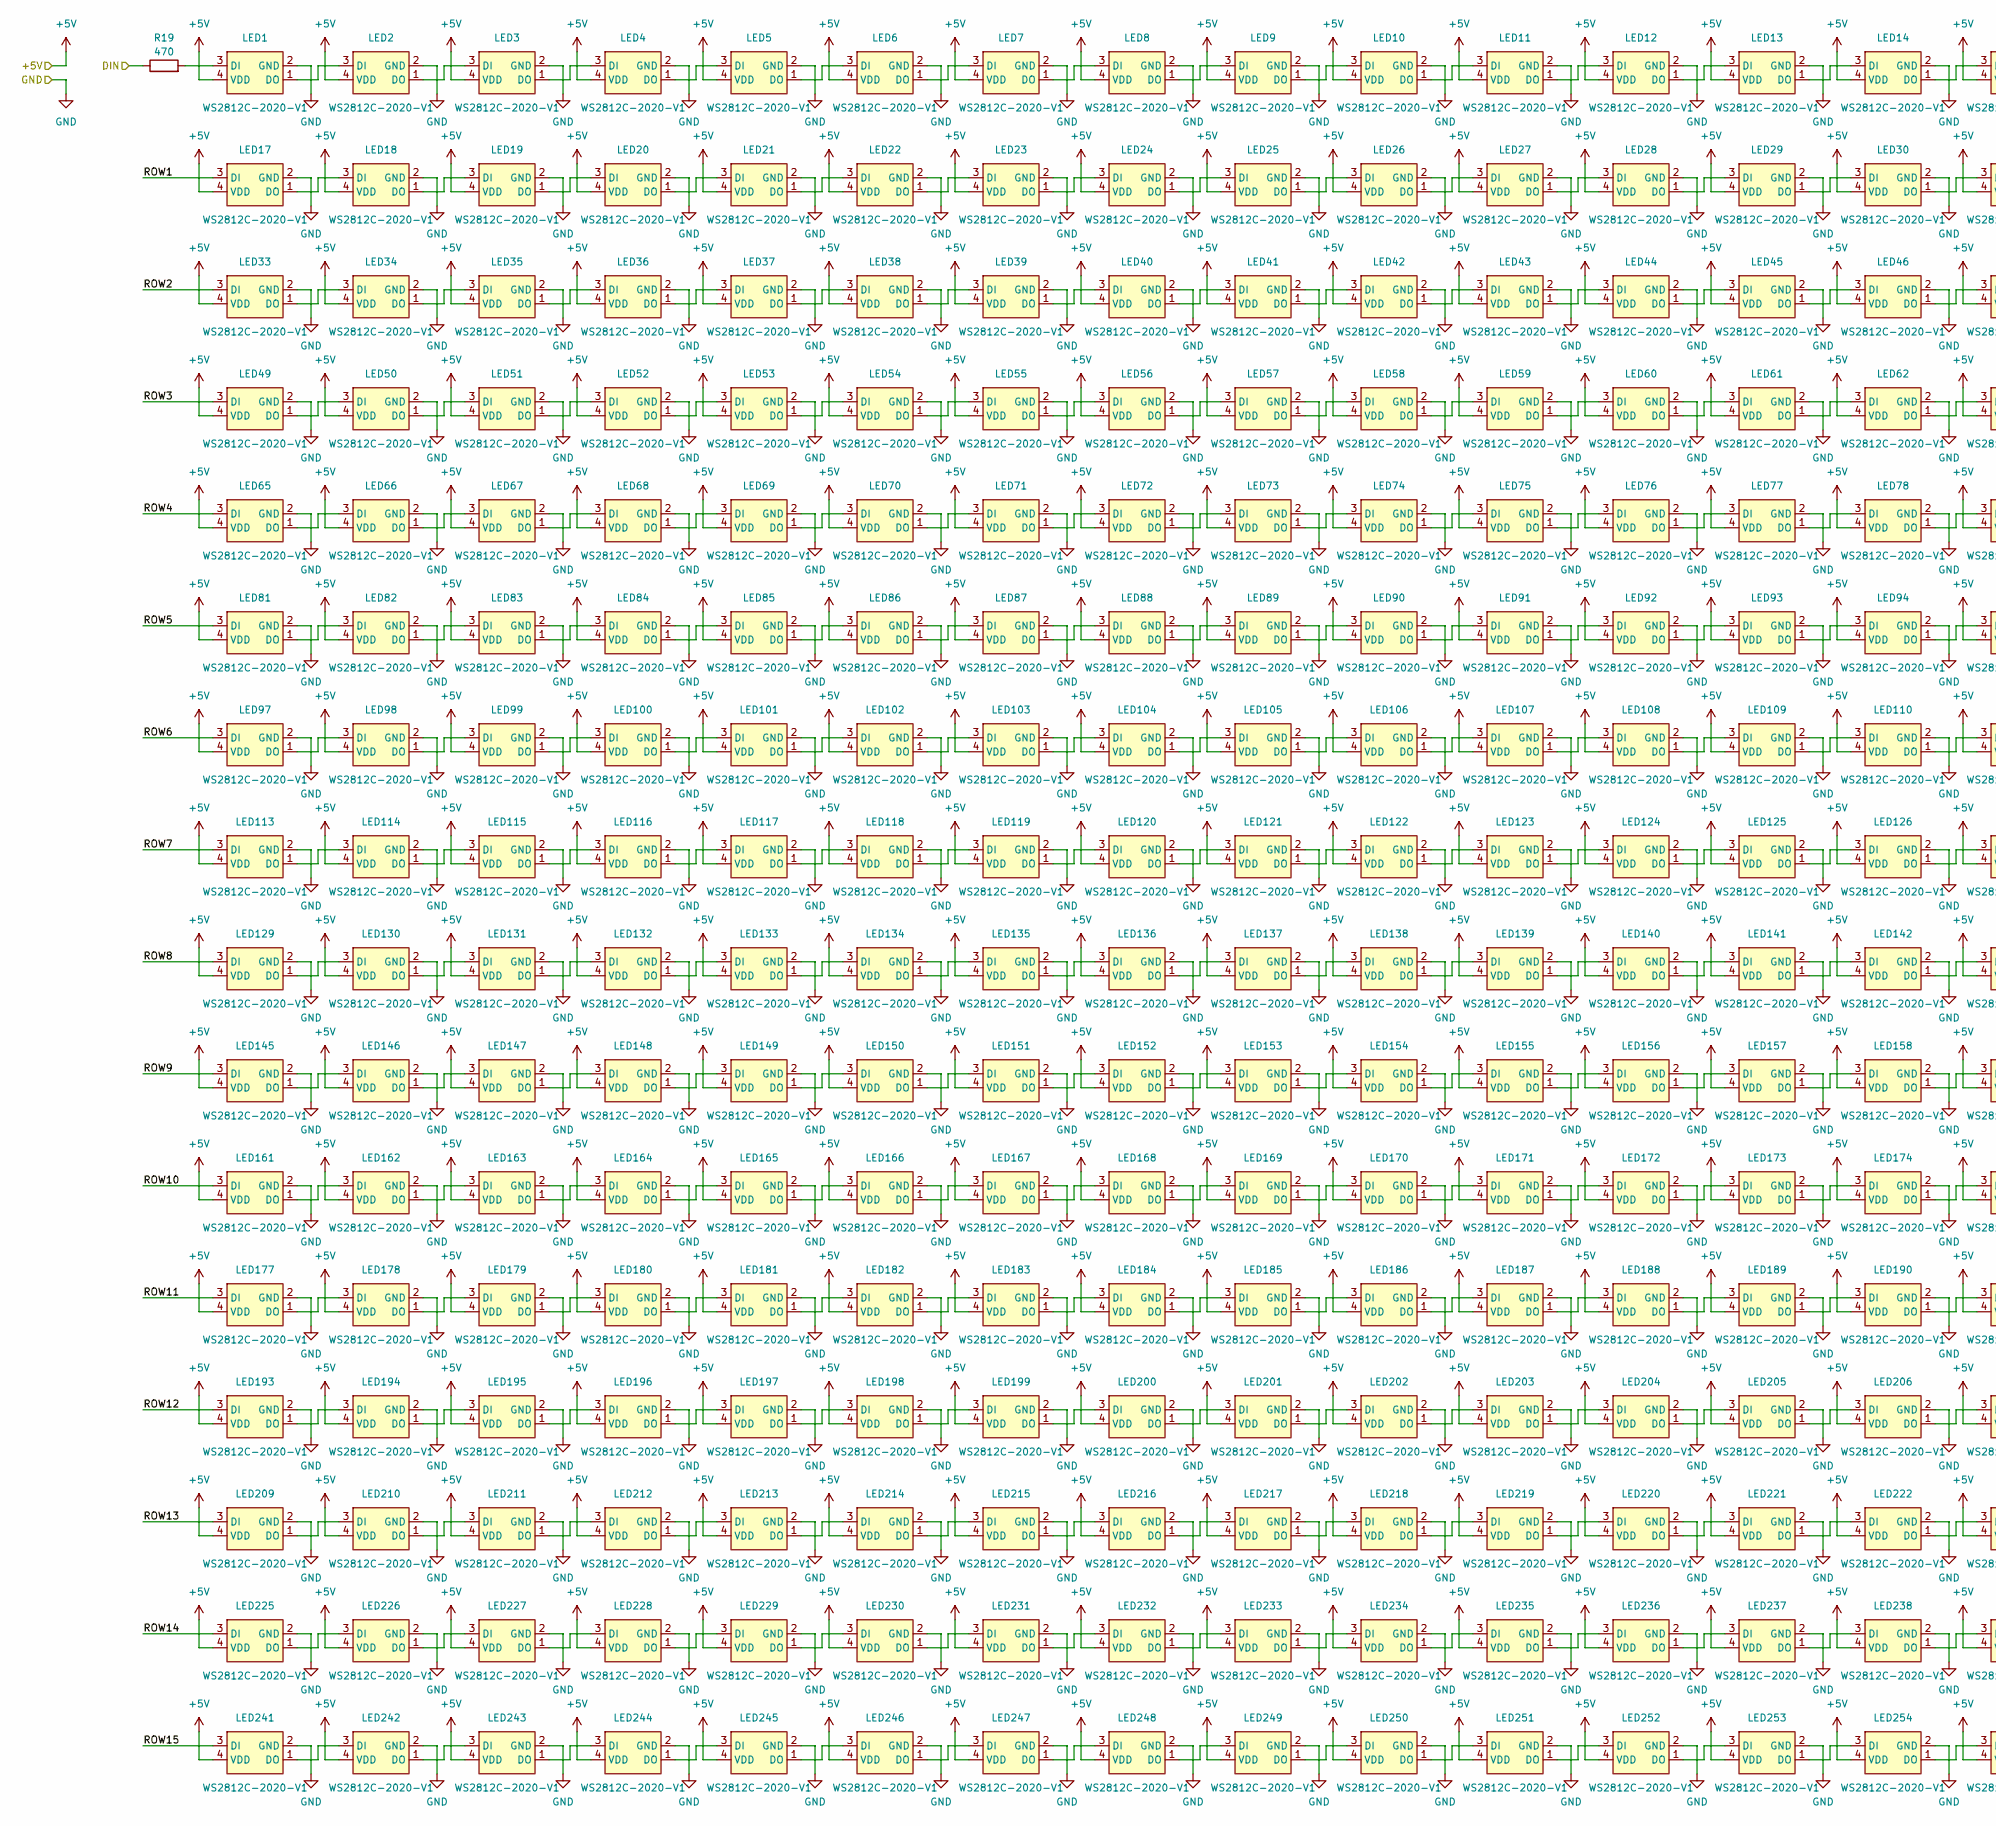
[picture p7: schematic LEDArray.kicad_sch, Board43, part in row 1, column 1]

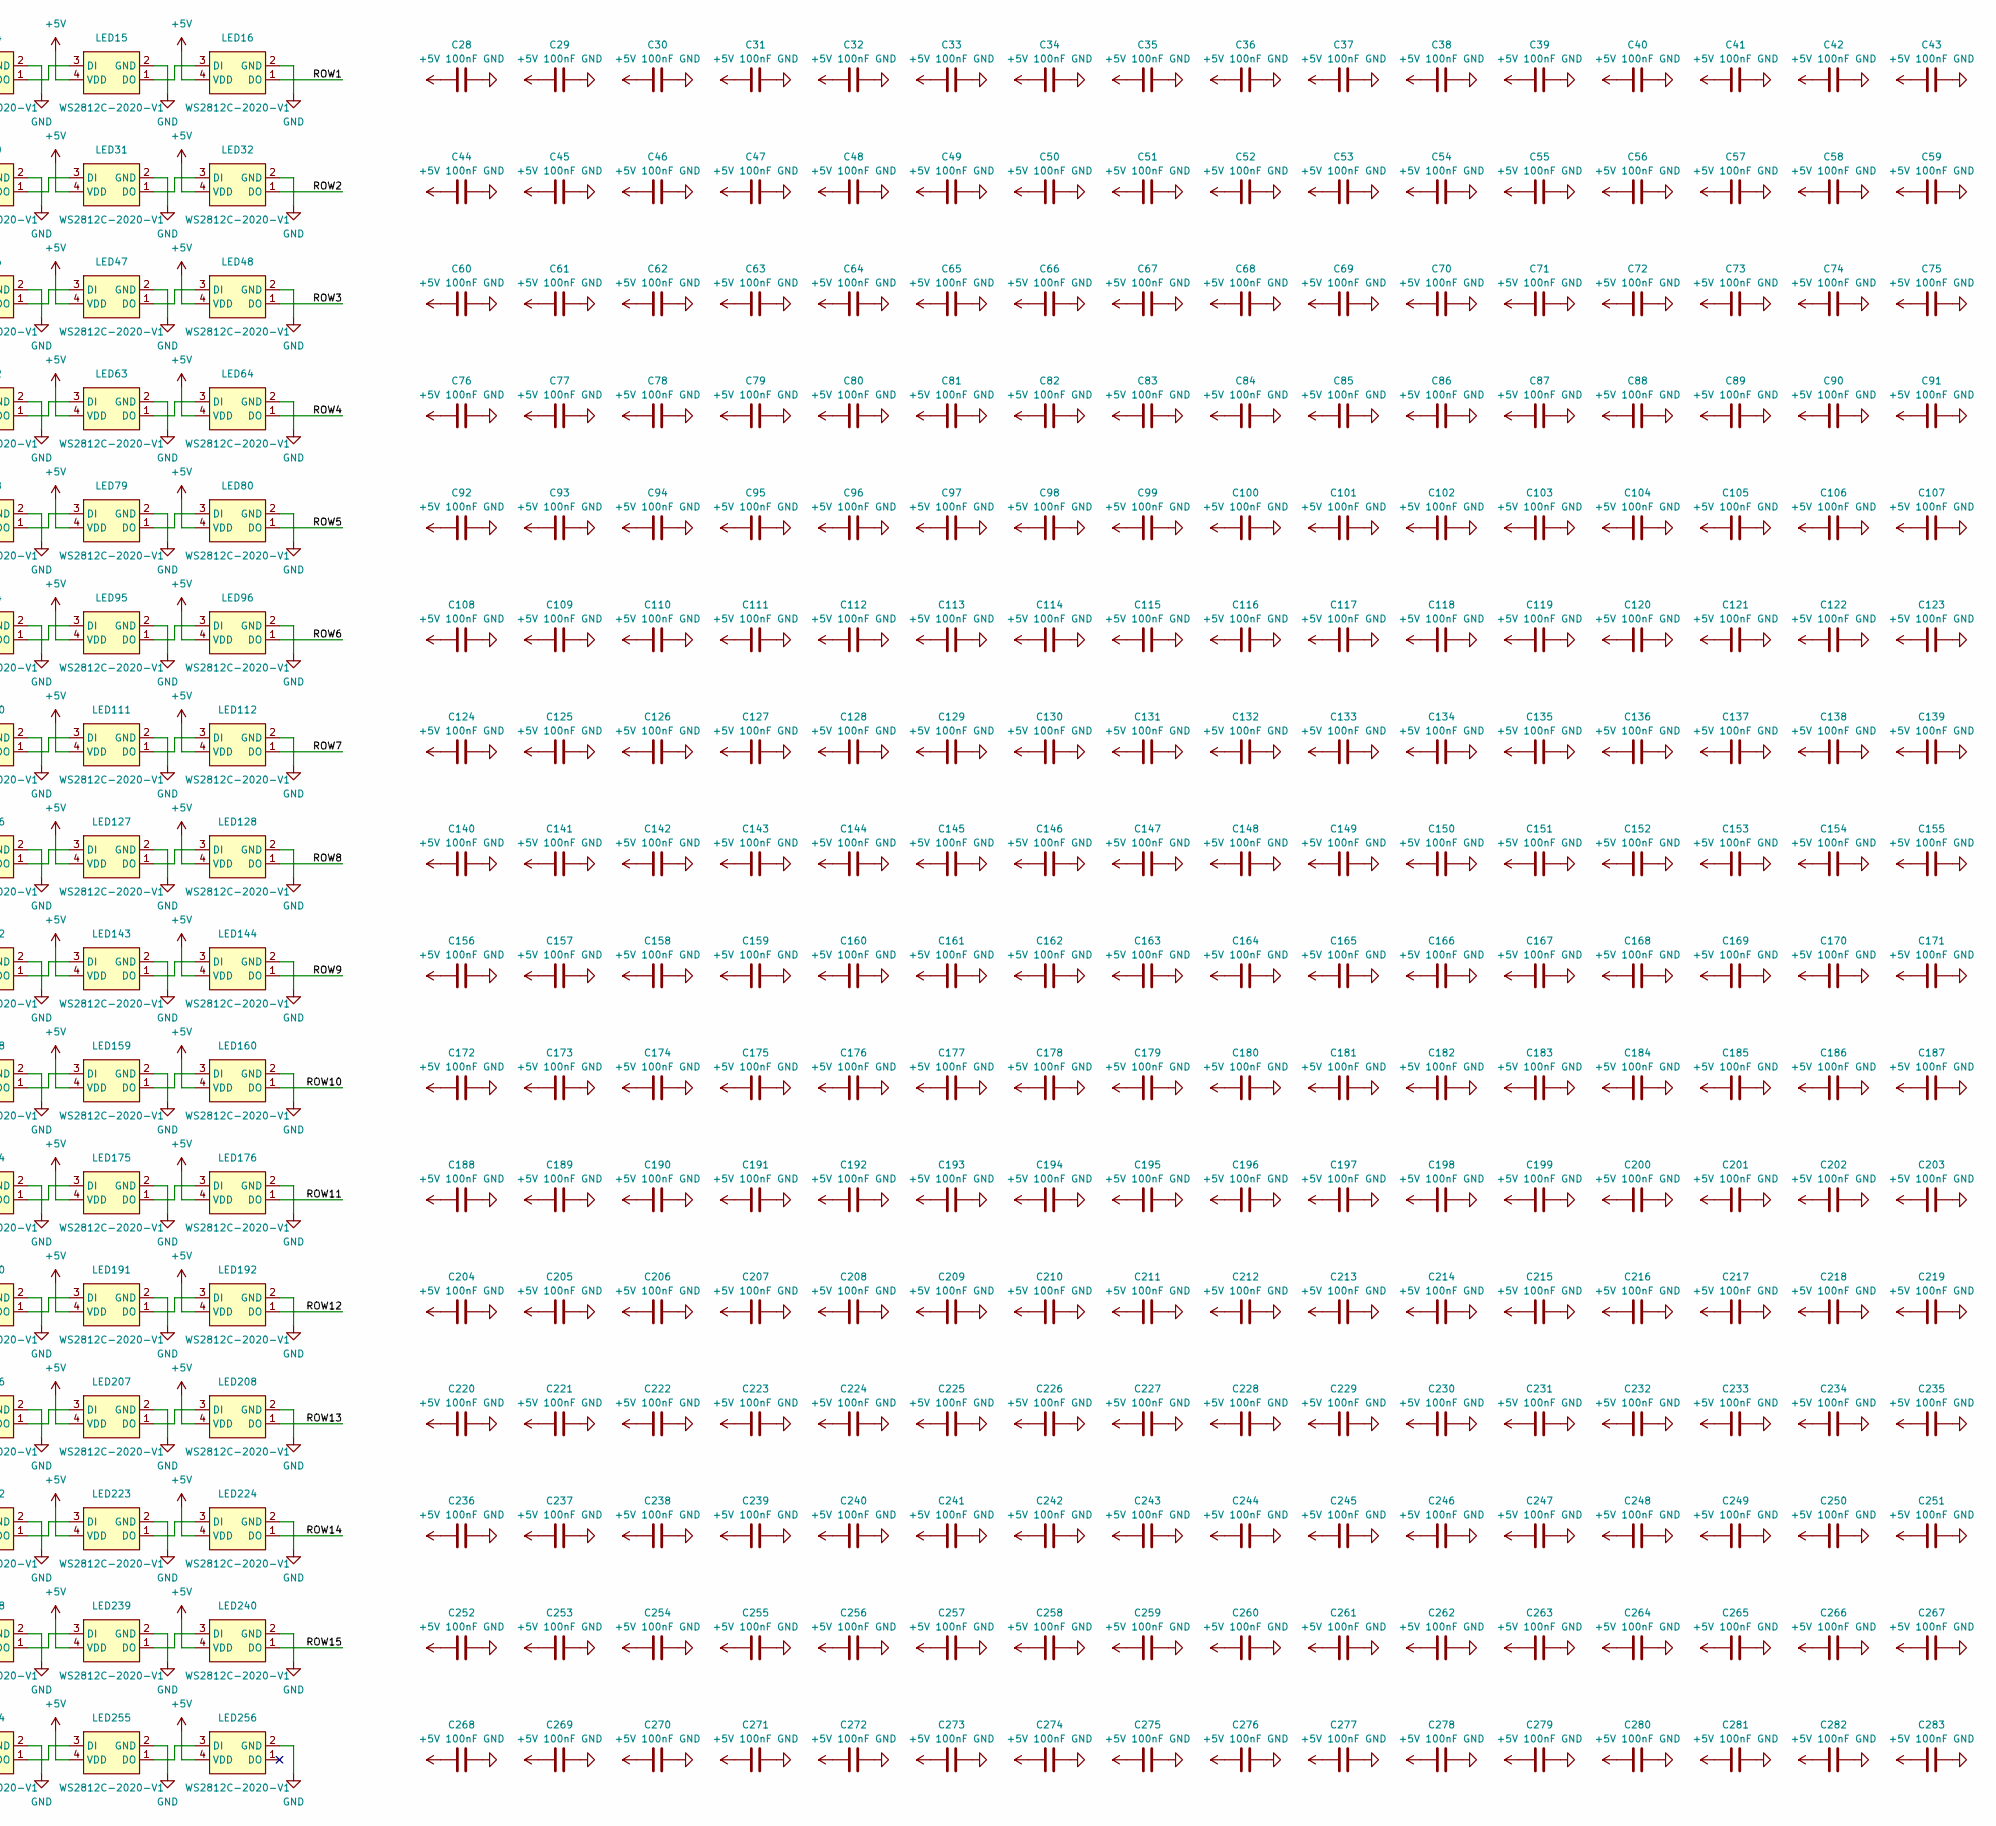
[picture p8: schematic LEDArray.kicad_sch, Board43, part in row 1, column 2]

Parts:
C28, C29, C30, C31, C32, C33, C34, C35, C36, C37, C38, C39, C40, C41, C42, C43, C44, C45, C46, C47, C48, C49, C50, C51, C52, C53, C54, C55, C56, C57, C58, C59, C60, C61, C62, C63, C64, C65, C66, C67, C68, C69, C70, C71, C72, C73, C74, C75, C76, C77, C78, C79, C80, C81, C82, C83, C84, C85, C86, C87, C88, C89, C90, C91, C92, C93, C94, C95, C96, C97, C98, C99, C100, C101, C102, C103, C104, C105, C106, C107, C108, C109, C110, C111, C112, C113, C114, C115, C116, C117, C118, C119, C120, C121, C122, C123, C124, C125, C126, C127, C128, C129, C130, C131, C132, C133, C134, C135, C136, C137, C138, C139, C140, C141, C142, C143, C144, C145, C146, C147, C148, C149, C150, C151, C152, C153, C154, C155, C156, C157, C158, C159, C160, C161, C162, C163, C164, C165, C166, C167, C168, C169, C170, C171, C172, C173, C174, C175, C176, C177, C178, C179, C180, C181, C182, C183, C184, C185, C186, C187, C188, C189, C190, C191, C192, C193, C194, C195, C196, C197, C198, C199, C200, C201, C202, C203, C204, C205, C206, C207, C208, C209, C210, C211, C212, C213, C214, C215, C216, C217, C218, C219, C220, C221, C222, C223, C224, C225, C226, C227, C228, C229, C230, C231, C232, C233, C234, C235, C236, C237, C238, C239, C240, C241, C242, C243, C244, C245, C246, C247, C248, C249, C250, C251, C252, C253, C254, C255, C256, C257, C258, C259, C260, C261, C262, C263, C264, C265, C266, C267, C268, C269, C270, C271, C272, C273, C274, C275, C276, C277, C278, C279, C280, C281, C282, C283: 100nF; C_0201_0603Metric; LCSC C668346
LED1, LED2, LED3, LED4, LED5, LED6, LED7, LED8, LED9, LED10, LED11, LED12, LED13, LED14, LED15, LED16, LED17, LED18, LED19, LED20, LED21, LED22, LED23, LED24, LED25, LED26, LED27, LED28, LED29, LED30, LED31, LED32, LED33, LED34, LED35, LED36, LED37, LED38, LED39, LED40, LED41, LED42, LED43, LED44, LED45, LED46, LED47, LED48, LED49, LED50, LED51, LED52, LED53, LED54, LED55, LED56, LED57, LED58, LED59, LED60, LED61, LED62, LED63, LED64, LED65, LED66, LED67, LED68, LED69, LED70, LED71, LED72, LED73, LED74, LED75, LED76, LED77, LED78, LED79, LED80, LED81, LED82, LED83, LED84, LED85, LED86, LED87, LED88, LED89, LED90, LED91, LED92, LED93, LED94, LED95, LED96, LED97, LED98, LED99, LED100, LED101, LED102, LED103, LED104, LED105, LED106, LED107, LED108, LED109, LED110, LED111, LED112, LED113, LED114, LED115, LED116, LED117, LED118, LED119, LED120, LED121, LED122, LED123, LED124, LED125, LED126, LED127, LED128, LED129, LED130, LED131, LED132, LED133, LED134, LED135, LED136, LED137, LED138, LED139, LED140, LED141, LED142, LED143, LED144, LED145, LED146, LED147, LED148, LED149, LED150, LED151, LED152, LED153, LED154, LED155, LED156, LED157, LED158, LED159, LED160, LED161, LED162, LED163, LED164, LED165, LED166, LED167, LED168, LED169, LED170, LED171, LED172, LED173, LED174, LED175, LED176, LED177, LED178, LED179, LED180, LED181, LED182, LED183, LED184, LED185, LED186, LED187, LED188, LED189, LED190, LED191, LED192, LED193, LED194, LED195, LED196, LED197, LED198, LED199, LED200, LED201, LED202, LED203, LED204, LED205, LED206, LED207, LED208, LED209, LED210, LED211, LED212, LED213, LED214, LED215, LED216, LED217, LED218, LED219, LED220, LED221, LED222, LED223, LED224, LED225, LED226, LED227, LED228, LED229, LED230, LED231, LED232, LED233, LED234, LED235, LED236, LED237, LED238, LED239, LED240, LED241, LED242, LED243, LED244, LED245, LED246, LED247, LED248, LED249, LED250, LED251, LED252, LED253, LED254, LED255, LED256: WS2812C-2020-V1; LCSC C2976072
R19: 470; R_0201_0603Metric; LCSC C473464

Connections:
+5V: C28.1, C29.1, C30.1, C31.1, C32.1, C33.1, C34.1, C35.1, C36.1, C37.1, C38.1, C39.1, C40.1, C41.1, C42.1, C43.1, C44.1, C45.1, C46.1, C47.1, C48.1, C49.1, C50.1, C51.1, C52.1, C53.1, C54.1, C55.1, C56.1, C57.1, C58.1, C59.1, C60.1, C61.1, C62.1, C63.1, C64.1, C65.1, C66.1, C67.1, C68.1, C69.1, C70.1, C71.1, C72.1, C73.1, C74.1, C75.1, C76.1, C77.1, C78.1, C79.1, C80.1, C81.1, C82.1, C83.1, C84.1, C85.1, C86.1, C87.1, C88.1, C89.1, C90.1, C91.1, C92.1, C93.1, C94.1, C95.1, C96.1, C97.1, C98.1, C99.1, C100.1, C101.1, C102.1, C103.1, C104.1, C105.1, C106.1, C107.1, C108.1, C109.1, C110.1, C111.1, C112.1, C113.1, C114.1, C115.1, C116.1, C117.1, C118.1, C119.1, C120.1, C121.1, C122.1, C123.1, C124.1, C125.1, C126.1, C127.1, C128.1, C129.1, C130.1, C131.1, C132.1, C133.1, C134.1, C135.1, C136.1, C137.1, C138.1, C139.1, C140.1, C141.1, C142.1, C143.1, C144.1, C145.1, C146.1, C147.1, C148.1, C149.1, C150.1, C151.1, C152.1, C153.1, C154.1, C155.1, C156.1, C157.1, C158.1, C159.1, C160.1, C161.1, C162.1, C163.1, C164.1, C165.1, C166.1, C167.1, C168.1, C169.1, C170.1, C171.1, C172.1, C173.1, C174.1, C175.1, C176.1, C177.1, C178.1, C179.1, C180.1, C181.1, C182.1, C183.1, C184.1, C185.1, C186.1, C187.1, C188.1, C189.1, C190.1, C191.1, C192.1, C193.1, C194.1, C195.1, C196.1, C197.1, C198.1, C199.1, C200.1, C201.1, C202.1, C203.1, C204.1, C205.1, C206.1, C207.1, C208.1, C209.1, C210.1, C211.1, C212.1, C213.1, C214.1, C215.1, C216.1, C217.1, C218.1, C219.1, C220.1, C221.1, C222.1, C223.1, C224.1, C225.1, C226.1, C227.1, C228.1, C229.1, C230.1, C231.1, C232.1, C233.1, C234.1, C235.1, C236.1, C237.1, C238.1, C239.1, C240.1, C241.1, C242.1, C243.1, C244.1, C245.1, C246.1, C247.1, C248.1, C249.1, C250.1, C251.1, C252.1, C253.1, C254.1, C255.1, C256.1, C257.1, C258.1, C259.1, C260.1, C261.1, C262.1, C263.1, C264.1, C265.1, C266.1, C267.1, C268.1, C269.1, C270.1, C271.1, C272.1, C273.1, C274.1, C275.1, C276.1, C277.1, C278.1, C279.1, C280.1, C281.1, C282.1, C283.1, LED1.4 (VDD), LED2.4 (VDD), LED3.4 (VDD), LED4.4 (VDD), LED5.4 (VDD), LED6.4 (VDD), LED7.4 (VDD), LED8.4 (VDD), LED9.4 (VDD), LED10.4 (VDD), LED11.4 (VDD), LED12.4 (VDD), LED13.4 (VDD), LED14.4 (VDD), LED15.4 (VDD), LED16.4 (VDD), LED17.4 (VDD), LED18.4 (VDD), LED19.4 (VDD), LED20.4 (VDD), LED21.4 (VDD), LED22.4 (VDD), LED23.4 (VDD), LED24.4 (VDD), LED25.4 (VDD), LED26.4 (VDD), LED27.4 (VDD), LED28.4 (VDD), LED29.4 (VDD), LED30.4 (VDD), LED31.4 (VDD), LED32.4 (VDD), LED33.4 (VDD), LED34.4 (VDD), LED35.4 (VDD), LED36.4 (VDD), LED37.4 (VDD), LED38.4 (VDD), LED39.4 (VDD), LED40.4 (VDD), LED41.4 (VDD), LED42.4 (VDD), LED43.4 (VDD), LED44.4 (VDD), LED45.4 (VDD), LED46.4 (VDD), LED47.4 (VDD), LED48.4 (VDD), LED49.4 (VDD), LED50.4 (VDD), LED51.4 (VDD), LED52.4 (VDD), LED53.4 (VDD), LED54.4 (VDD), LED55.4 (VDD), LED56.4 (VDD), LED57.4 (VDD), LED58.4 (VDD), LED59.4 (VDD), LED60.4 (VDD), LED61.4 (VDD), LED62.4 (VDD), LED63.4 (VDD), LED64.4 (VDD)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; also elsewhere on the board
/LED OUT: R19.1; also elsewhere on the board
/LEDArray/ROW1: LED16.1 (DO), LED17.3 (DI)
/LEDArray/ROW2: LED32.1 (DO), LED33.3 (DI)
/LEDArray/ROW3: LED48.1 (DO), LED49.3 (DI)
/LEDArray/ROW4: LED64.1 (DO), LED65.3 (DI)
/LEDArray/ROW5: LED80.1 (DO), LED81.3 (DI)
/LEDArray/ROW6: LED96.1 (DO), LED97.3 (DI)
/LEDArray/ROW7: LED112.1 (DO), LED113.3 (DI)
/LEDArray/ROW8: LED128.1 (DO), LED129.3 (DI)
/LEDArray/ROW9: LED144.1 (DO), LED145.3 (DI)
/LEDArray/ROW10: LED160.1 (DO), LED161.3 (DI)
/LEDArray/ROW11: LED176.1 (DO), LED177.3 (DI)
/LEDArray/ROW12: LED192.1 (DO), LED193.3 (DI)
/LEDArray/ROW13: LED208.1 (DO), LED209.3 (DI)
/LEDArray/ROW14: LED224.1 (DO), LED225.3 (DI)
/LEDArray/ROW15: LED240.1 (DO), LED241.3 (DI)
GND: C28.2, C29.2, C30.2, C31.2, C32.2, C33.2, C34.2, C35.2, C36.2, C37.2, C38.2, C39.2, C40.2, C41.2, C42.2, C43.2, C44.2, C45.2, C46.2, C47.2, C48.2, C49.2, C50.2, C51.2, C52.2, C53.2, C54.2, C55.2, C56.2, C57.2, C58.2, C59.2, C60.2, C61.2, C62.2, C63.2, C64.2, C65.2, C66.2, C67.2, C68.2, C69.2, C70.2, C71.2, C72.2, C73.2, C74.2, C75.2, C76.2, C77.2, C78.2, C79.2, C80.2, C81.2, C82.2, C83.2, C84.2, C85.2, C86.2, C87.2, C88.2, C89.2, C90.2, C91.2, C92.2, C93.2, C94.2, C95.2, C96.2, C97.2, C98.2, C99.2, C100.2, C101.2, C102.2, C103.2, C104.2, C105.2, C106.2, C107.2, C108.2, C109.2, C110.2, C111.2, C112.2, C113.2, C114.2, C115.2, C116.2, C117.2, C118.2, C119.2, C120.2, C121.2, C122.2, C123.2, C124.2, C125.2, C126.2, C127.2, C128.2, C129.2, C130.2, C131.2, C132.2, C133.2, C134.2, C135.2, C136.2, C137.2, C138.2, C139.2, C140.2, C141.2, C142.2, C143.2, C144.2, C145.2, C146.2, C147.2, C148.2, C149.2, C150.2, C151.2, C152.2, C153.2, C154.2, C155.2, C156.2, C157.2, C158.2, C159.2, C160.2, C161.2, C162.2, C163.2, C164.2, C165.2, C166.2, C167.2, C168.2, C169.2, C170.2, C171.2, C172.2, C173.2, C174.2, C175.2, C176.2, C177.2, C178.2, C179.2, C180.2, C181.2, C182.2, C183.2, C184.2, C185.2, C186.2, C187.2, C188.2, C189.2, C190.2, C191.2, C192.2, C193.2, C194.2, C195.2, C196.2, C197.2, C198.2, C199.2, C200.2, C201.2, C202.2, C203.2, C204.2, C205.2, C206.2, C207.2, C208.2, C209.2, C210.2, C211.2, C212.2, C213.2, C214.2, C215.2, C216.2, C217.2, C218.2, C219.2, C220.2, C221.2, C222.2, C223.2, C224.2, C225.2, C226.2, C227.2, C228.2, C229.2, C230.2, C231.2, C232.2, C233.2, C234.2, C235.2, C236.2, C237.2, C238.2, C239.2, C240.2, C241.2, C242.2, C243.2, C244.2, C245.2, C246.2, C247.2, C248.2, C249.2, C250.2, C251.2, C252.2, C253.2, C254.2, C255.2, C256.2, C257.2, C258.2, C259.2, C260.2, C261.2, C262.2, C263.2, C264.2, C265.2, C266.2, C267.2, C268.2, C269.2, C270.2, C271.2, C272.2, C273.2, C274.2, C275.2, C276.2, C277.2, C278.2, C279.2, C280.2, C281.2, C282.2, C283.2, LED1.2 (GND), LED2.2 (GND), LED3.2 (GND), LED4.2 (GND), LED5.2 (GND), LED6.2 (GND), LED7.2 (GND), LED8.2 (GND), LED9.2 (GND), LED10.2 (GND), LED11.2 (GND), LED12.2 (GND), LED13.2 (GND), LED14.2 (GND), LED15.2 (GND), LED16.2 (GND), LED17.2 (GND), LED18.2 (GND), LED19.2 (GND), LED20.2 (GND), LED21.2 (GND), LED22.2 (GND), LED23.2 (GND), LED24.2 (GND), LED25.2 (GND), LED26.2 (GND), LED27.2 (GND), LED28.2 (GND), LED29.2 (GND), LED30.2 (GND), LED31.2 (GND), LED32.2 (GND), LED33.2 (GND), LED34.2 (GND), LED35.2 (GND), LED36.2 (GND), LED37.2 (GND), LED38.2 (GND), LED39.2 (GND), LED40.2 (GND), LED41.2 (GND), LED42.2 (GND), LED43.2 (GND), LED44.2 (GND), LED45.2 (GND), LED46.2 (GND), LED47.2 (GND), LED48.2 (GND), LED49.2 (GND), LED50.2 (GND), LED51.2 (GND), LED52.2 (GND), LED53.2 (GND), LED54.2 (GND), LED55.2 (GND), LED56.2 (GND), LED57.2 (GND), LED58.2 (GND), LED59.2 (GND), LED60.2 (GND), LED61.2 (GND), LED62.2 (GND), LED63.2 (GND), LED64.2 (GND)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; also elsewhere on the board
unnamed: LED1.3 (DI), R19.2
unnamed: LED1.1 (DO), LED2.3 (DI)
unnamed: LED2.1 (DO), LED3.3 (DI)
unnamed: LED3.1 (DO), LED4.3 (DI)
unnamed: LED4.1 (DO), LED5.3 (DI)
unnamed: LED5.1 (DO), LED6.3 (DI)
unnamed: LED6.1 (DO), LED7.3 (DI)
unnamed: LED7.1 (DO), LED8.3 (DI)
unnamed: LED8.1 (DO), LED9.3 (DI)
unnamed: LED9.1 (DO), LED10.3 (DI)
unnamed: LED10.1 (DO), LED11.3 (DI)
unnamed: LED11.1 (DO), LED12.3 (DI)
unnamed: LED12.1 (DO), LED13.3 (DI)
unnamed: LED13.1 (DO), LED14.3 (DI)
unnamed: LED14.1 (DO), LED15.3 (DI)
unnamed: LED15.1 (DO), LED16.3 (DI)
unnamed: LED17.1 (DO), LED18.3 (DI)
unnamed: LED18.1 (DO), LED19.3 (DI)
unnamed: LED19.1 (DO), LED20.3 (DI)
unnamed: LED20.1 (DO), LED21.3 (DI)
unnamed: LED21.1 (DO), LED22.3 (DI)
unnamed: LED22.1 (DO), LED23.3 (DI)
unnamed: LED23.1 (DO), LED24.3 (DI)
unnamed: LED24.1 (DO), LED25.3 (DI)
unnamed: LED25.1 (DO), LED26.3 (DI)
unnamed: LED26.1 (DO), LED27.3 (DI)
unnamed: LED27.1 (DO), LED28.3 (DI)
unnamed: LED28.1 (DO), LED29.3 (DI)
unnamed: LED29.1 (DO), LED30.3 (DI)
unnamed: LED30.1 (DO), LED31.3 (DI)
unnamed: LED31.1 (DO), LED32.3 (DI)
unnamed: LED33.1 (DO), LED34.3 (DI)
unnamed: LED34.1 (DO), LED35.3 (DI)
unnamed: LED35.1 (DO), LED36.3 (DI)
unnamed: LED36.1 (DO), LED37.3 (DI)
unnamed: LED37.1 (DO), LED38.3 (DI)
unnamed: LED38.1 (DO), LED39.3 (DI)
unnamed: LED39.1 (DO), LED40.3 (DI)
unnamed: LED40.1 (DO), LED41.3 (DI)
unnamed: LED41.1 (DO), LED42.3 (DI)
unnamed: LED42.1 (DO), LED43.3 (DI)
unnamed: LED43.1 (DO), LED44.3 (DI)
unnamed: LED44.1 (DO), LED45.3 (DI)
unnamed: LED45.1 (DO), LED46.3 (DI)
unnamed: LED46.1 (DO), LED47.3 (DI)
unnamed: LED47.1 (DO), LED48.3 (DI)
unnamed: LED49.1 (DO), LED50.3 (DI)
unnamed: LED50.1 (DO), LED51.3 (DI)
unnamed: LED51.1 (DO), LED52.3 (DI)
unnamed: LED52.1 (DO), LED53.3 (DI)
unnamed: LED53.1 (DO), LED54.3 (DI)
unnamed: LED54.1 (DO), LED55.3 (DI)
unnamed: LED55.1 (DO), LED56.3 (DI)
unnamed: LED56.1 (DO), LED57.3 (DI)
unnamed: LED57.1 (DO), LED58.3 (DI)
unnamed: LED58.1 (DO), LED59.3 (DI)
unnamed: LED59.1 (DO), LED60.3 (DI)
unnamed: LED60.1 (DO), LED61.3 (DI)
unnamed: LED61.1 (DO), LED62.3 (DI)
unnamed: LED62.1 (DO), LED63.3 (DI)
unnamed: LED63.1 (DO), LED64.3 (DI)
unnamed: LED65.1 (DO), LED66.3 (DI)
unnamed: LED66.1 (DO), LED67.3 (DI)
unnamed: LED67.1 (DO), LED68.3 (DI)
unnamed: LED68.1 (DO), LED69.3 (DI)
unnamed: LED69.1 (DO), LED70.3 (DI)
unnamed: LED70.1 (DO), LED71.3 (DI)
unnamed: LED71.1 (DO), LED72.3 (DI)
unnamed: LED72.1 (DO), LED73.3 (DI)
unnamed: LED73.1 (DO), LED74.3 (DI)
unnamed: LED74.1 (DO), LED75.3 (DI)
unnamed: LED75.1 (DO), LED76.3 (DI)
unnamed: LED76.1 (DO), LED77.3 (DI)
unnamed: LED77.1 (DO), LED78.3 (DI)
unnamed: LED78.1 (DO), LED79.3 (DI)
unnamed: LED79.1 (DO), LED80.3 (DI)
unnamed: LED81.1 (DO), LED82.3 (DI)
unnamed: LED82.1 (DO), LED83.3 (DI)
unnamed: LED83.1 (DO), LED84.3 (DI)
unnamed: LED84.1 (DO), LED85.3 (DI)
unnamed: LED85.1 (DO), LED86.3 (DI)
unnamed: LED86.1 (DO), LED87.3 (DI)
unnamed: LED87.1 (DO), LED88.3 (DI)
unnamed: LED88.1 (DO), LED89.3 (DI)
unnamed: LED89.1 (DO), LED90.3 (DI)
unnamed: LED90.1 (DO), LED91.3 (DI)
unnamed: LED91.1 (DO), LED92.3 (DI)
unnamed: LED92.1 (DO), LED93.3 (DI)
unnamed: LED93.1 (DO), LED94.3 (DI)
unnamed: LED94.1 (DO), LED95.3 (DI)
unnamed: LED95.1 (DO), LED96.3 (DI)
unnamed: LED97.1 (DO), LED98.3 (DI)
unnamed: LED98.1 (DO), LED99.3 (DI)
unnamed: LED99.1 (DO), LED100.3 (DI)
unnamed: LED100.1 (DO), LED101.3 (DI)
unnamed: LED101.1 (DO), LED102.3 (DI)
unnamed: LED102.1 (DO), LED103.3 (DI)
unnamed: LED103.1 (DO), LED104.3 (DI)
unnamed: LED104.1 (DO), LED105.3 (DI)
unnamed: LED105.1 (DO), LED106.3 (DI)
unnamed: LED106.1 (DO), LED107.3 (DI)
unnamed: LED107.1 (DO), LED108.3 (DI)
unnamed: LED108.1 (DO), LED109.3 (DI)
unnamed: LED109.1 (DO), LED110.3 (DI)
unnamed: LED110.1 (DO), LED111.3 (DI)
unnamed: LED111.1 (DO), LED112.3 (DI)
unnamed: LED113.1 (DO), LED114.3 (DI)
unnamed: LED114.1 (DO), LED115.3 (DI)
unnamed: LED115.1 (DO), LED116.3 (DI)
unnamed: LED116.1 (DO), LED117.3 (DI)
unnamed: LED117.1 (DO), LED118.3 (DI)
unnamed: LED118.1 (DO), LED119.3 (DI)
unnamed: LED119.1 (DO), LED120.3 (DI)
unnamed: LED120.1 (DO), LED121.3 (DI)
unnamed: LED121.1 (DO), LED122.3 (DI)
unnamed: LED122.1 (DO), LED123.3 (DI)
unnamed: LED123.1 (DO), LED124.3 (DI)
unnamed: LED124.1 (DO), LED125.3 (DI)
unnamed: LED125.1 (DO), LED126.3 (DI)
unnamed: LED126.1 (DO), LED127.3 (DI)
unnamed: LED127.1 (DO), LED128.3 (DI)
unnamed: LED129.1 (DO), LED130.3 (DI)
unnamed: LED130.1 (DO), LED131.3 (DI)
unnamed: LED131.1 (DO), LED132.3 (DI)
unnamed: LED132.1 (DO), LED133.3 (DI)
unnamed: LED133.1 (DO), LED134.3 (DI)
unnamed: LED134.1 (DO), LED135.3 (DI)
unnamed: LED135.1 (DO), LED136.3 (DI)
unnamed: LED136.1 (DO), LED137.3 (DI)
unnamed: LED137.1 (DO), LED138.3 (DI)
unnamed: LED138.1 (DO), LED139.3 (DI)
unnamed: LED139.1 (DO), LED140.3 (DI)
unnamed: LED140.1 (DO), LED141.3 (DI)
unnamed: LED141.1 (DO), LED142.3 (DI)
unnamed: LED142.1 (DO), LED143.3 (DI)
unnamed: LED143.1 (DO), LED144.3 (DI)
unnamed: LED145.1 (DO), LED146.3 (DI)
unnamed: LED146.1 (DO), LED147.3 (DI)
unnamed: LED147.1 (DO), LED148.3 (DI)
unnamed: LED148.1 (DO), LED149.3 (DI)
unnamed: LED149.1 (DO), LED150.3 (DI)
unnamed: LED150.1 (DO), LED151.3 (DI)
unnamed: LED151.1 (DO), LED152.3 (DI)
unnamed: LED152.1 (DO), LED153.3 (DI)
unnamed: LED153.1 (DO), LED154.3 (DI)
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

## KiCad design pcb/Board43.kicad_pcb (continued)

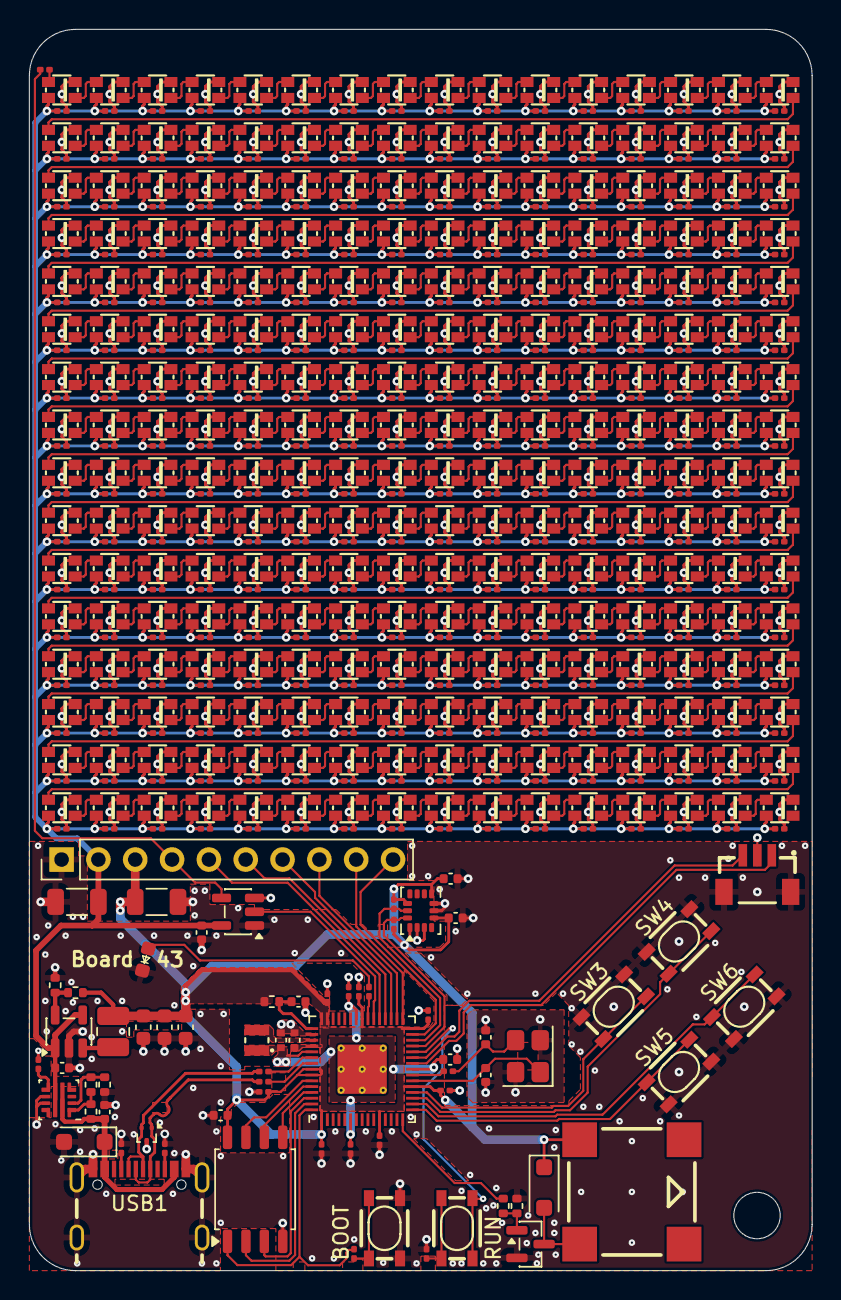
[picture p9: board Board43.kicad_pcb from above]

Board: 2 copper layers, 54.0 x 85.6 mm, 583 parts (0 on the bottom side), 307 nets.

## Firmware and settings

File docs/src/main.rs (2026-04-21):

use std::{
    error::Error,
    fs::{create_dir_all, write},
    path::PathBuf,
    process::exit,
};

use clap::Parser;
use env_logger::{Builder, Env};
use log::{error, info};
use tempdir::TempDir;
use tokio::{runtime::Runtime, select, signal::ctrl_c, spawn};
use typwriter::{
    CompileParams, FittingType, FormatParams, PdfStandard, compile, format, list_fonts, watch,
};

mod metadata;
mod nup;

#[derive(Parser)]
#[clap(about = "Compile and watch Typst documents")]
struct Cli {
    #[command(subcommand)]
    command: Command,
}

#[derive(Parser)]
enum Command {
    /// Compile Typst files to PDF.
    Compile {
        /// Path to input Typst file.
        #[arg(default_value = "reference-manual/main.typ")]
        input: PathBuf,

        /// Path to output directory.
        #[arg(short, long, default_value = "reference-manual")]
        output_dir: PathBuf,

        /// Additional directories to search for fonts.
        #[arg(long)]
        font_paths: Option<Vec<PathBuf>>,

        /// Path to metadata YAML file for PDF document properties.
        #[arg(long, default_value = "reference-manual/metadata.yml")]
        metadata: PathBuf,

        /// Generate n-up PDF (e.g. "1x2", "2x2").
        #[arg(long, value_name = "COLSxROWS")]
        nup: Option<String>,

        /// Flip n-up output page orientation.
        #[arg(long, requires = "nup")]
        flip: bool,
    },

    /// Watch Typst files and recompile on changes.
    Watch {
        /// Path to input Typst file.
        #[arg(default_value = "reference-manual/main.typ")]
        input: PathBuf,

        /// Additional directories to search for fonts.
        #[arg(long)]
        font_paths: Option<Vec<PathBuf>>,

        /// Application to open the output PDF file.
        #[arg(long, default_value = "Google Chrome.app")]
        app: String,

        /// PDF viewer fitting type.
        #[arg(long, value_parser = ["page", "width", "height"], default_value = "page")]
        fitting_type: String,
    },

    /// Format Typst files.
    Format {
        /// Path to input Typst file.
        #[arg(default_value = "reference-manual/main.typ")]
        input: PathBuf,

        /// Column width.
        #[arg(long, default_value = "80")]
        column: usize,
    },

    /// List available fonts.
    ListFonts {
        /// Additional directories to search for fonts.
        #[arg(long)]
        font_paths: Option<Vec<PathBuf>>,
    },
}

fn parse_nup(s: &str) -> Result<(u32, u32), String> {
    let parts: Vec<&str> = s.split('x').collect();
    if parts.len() != 2 {
        return Err(format!("expected COLSxROWS (e.g. 1x2), got {s}"));
    }
    let cols = parts[0].parse::<u32>().map_err(|e| e.to_string())?;
    let rows = parts[1].parse::<u32>().map_err(|e| e.to_string())?;
    Ok((cols, rows))
}

fn main() -> Result<(), Box<dyn Error>> {
    Builder::from_env(Env::default().default_filter_or("info")).init();
    let cli = Cli::parse();

    match cli.command {
        Command::Compile { input, output_dir, font_paths, metadata: metadata_path, nup: nup_opt, flip } => {
            create_dir_all(&output_dir)?;
            let output_dir = output_dir.canonicalize()?;
            let input = input.canonicalize()?;
            let stem = match input.file_stem().unwrap().to_str().unwrap() {
                "main" => input.parent().unwrap().file_name().unwrap().to_string_lossy(),
                other => other.into(),
            };
            let output = output_dir.join(format!("{stem}.pdf"));
            let params = CompileParams {
                input: input.clone(),
                output: output.clone(),
                font_paths: font_paths.unwrap_or_default(),
                dict: vec![],
                ppi: None,
                package_path: None,
                package_cache_path: None,
                pdf_standards: Some(vec![PdfStandard::V1_7]),
            };

            info!(r#"Compiling "{}""#, input.display());
            match compile(&params) {
                Ok(duration) => {
                    info!(r#"Compiled "{}" in {duration:?}"#, params.output.display())
                }
                Err(why) => {
                    error!("{why}");
                    exit(1);
                }
            }

            info!(r#"Applying metadata from "{}""#, metadata_path.display());
            let doc = metadata::load_metadata(&metadata_path)?;
            metadata::apply_metadata(&output, &doc)?;

            if let Some(ref nup_str) = nup_opt {
                let (cols, rows) = parse_nup(nup_str)?;
                let nup_output = output_dir.join(format!("{stem}-{cols}x{rows}.pdf"));
                nup::nup(&output, &nup_output, cols, rows, flip)?;
            }
        }

        Command::Watch { input, font_paths, app, fitting_type } => {
            let input = input.canonicalize()?;
            let temp_dir = TempDir::new("docs")?;
            info!("Temporary directory: {:?}", temp_dir.path());

            let params = CompileParams {
                input: input.clone(),
                output: temp_dir.path().join("watch.pdf"),
                font_paths: font_paths.unwrap_or_default(),
                dict: vec![],
                ppi: None,
                package_path: None,
                package_cache_path: None,
                pdf_standards: Some(vec![PdfStandard::V1_7]),
            };

            let rt = Runtime::new()?;
            rt.block_on(async {
                let handle = spawn(async move {
                    if let Err(e) = watch(&params, true, Some(&app), Some(FittingType::from(fitting_type.as_str()))).await
                    {
                        error!("Watch error for {:?}: {e}", params.input);
                    }
                });

                select! {
                    _ = ctrl_c() => {
                        info!("Shutting down...");
                    }
                    _ = handle => {}
                }
            });
        }

        Command::Format { input, column } => {
            if !input.exists() {
                error!(r#""{}" not found"#, input.display());
                exit(1);
            }
            match format(&FormatParams { input: input.clone(), column, tab_spaces: 2 }) {
                Ok(s) => {
                    write(&input, s)?;
                    info!(r#"Formatted "{}""#, input.display());
                }
                Err(why) => error!("{why:#?}"),
            }
        }

        Command::ListFonts { font_paths } => {
            let list = list_fonts(&font_paths.unwrap_or_default());
            for (family, fontinfo) in &list {
                println!("{family}:");
                let mut variants: Vec<_> = fontinfo
                    .iter()
                    .map(|info| {
                        format!(
                            "  - Style: {:?}, Weight: {:?}, Stretch: {:?}",
                            info.variant.style, info.variant.weight, info.variant.stretch
                        )
                    })
                    .collect();
                variants.sort();
                for v in variants {
                    println!("{v}");
                }
            }
        }
    }

    Ok(())
}

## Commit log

2026-04-21 hello world
    [Board43.kicad_pcb, Board43.kicad_sch, LEDArray.kicad_sch]
2026-04-22 refactor: add PCB licenses
    Rename symbol and footprint libraries from Board43 to Board43_KiCad
    to clarify they are project-specific KiCad libraries. Update library
    tables, schematic, and PCB references accordingly.
    Add CERN-OHL-W-2.0 and CC-BY-SA-4.0 license files for the PCB design.
    [Board43.kicad_pcb, Board43.kicad_sch]
2026-04-23 feat: add board43-image-transformer crate
    Provides a Rust library, CLI, and WASM module that converts arbitrary
    images into 16×16 RGB data for Board43's WS2812 LED matrix, with
    letterboxing to preserve aspect ratio and gamma correction for LED
    output.
2026-04-23 docs: clarify image upload uses board43-image-transformer WASM
